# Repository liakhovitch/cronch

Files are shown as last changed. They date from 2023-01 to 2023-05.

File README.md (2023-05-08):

# Crönch!
Not-entirely-sane digital delay pedal

**Note: This project is a work in progress!**

## What is this?
Crönch is a hardware audio effects processor unit, inspired by the Sonic Charge Permut8 software plugin. For a more detailed explanation, see [the proposal document](proposal/proposal.pdf).

Some key points:
- Hardware designed in KiCAD
- Firmware written in Rust
- Based on the RP2040 microcontroller and TI TLV320AIC3254 audio CODEC
- Runs at a 192KHz audio sampling rate

## Repository map
[Schematic](pcb/effectpedal/fabrication/schematic.pdf)

[Firmware](firmware/src)

[Original proposal](proposal/proposal.pdf)

## Todo
- [x] Preliminary design
- [X] Choosing components
- [X] Electrical design (schematic)
- [X] PCB design
- [X] Hardware assembly
- [X] Basic hardware test (MCU can read/write from each external peripheral)
- [X] Full hardware test (MCU can access all features of each external peripheral)
- [X] Multicore concurrency primitives
- [X] Front panel UI
- [ ] All hardware driver code complete
- [ ] Basic functionality (Sample incoming audio, write it to the buffer, then immediately send it back to the CODEC)
- [ ] All operators implemented
- [ ] All audio knobs (mix, feedback, gain, etc) implemented
- [ ] Variable clock rate

## Images
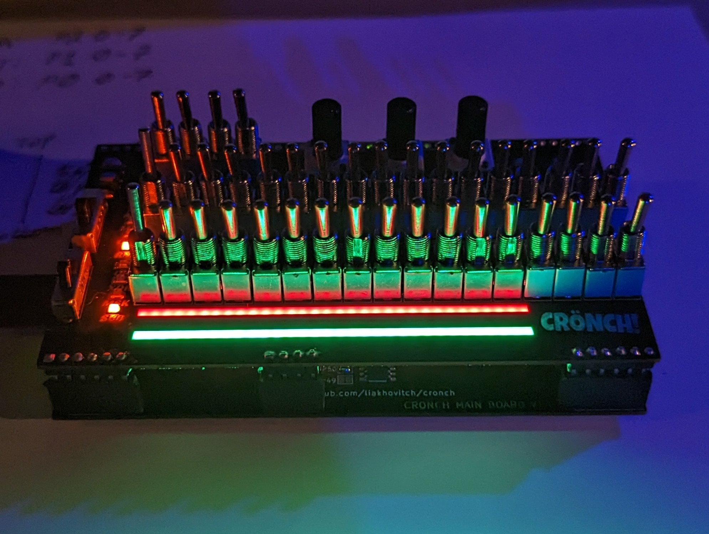
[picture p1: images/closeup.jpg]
Side

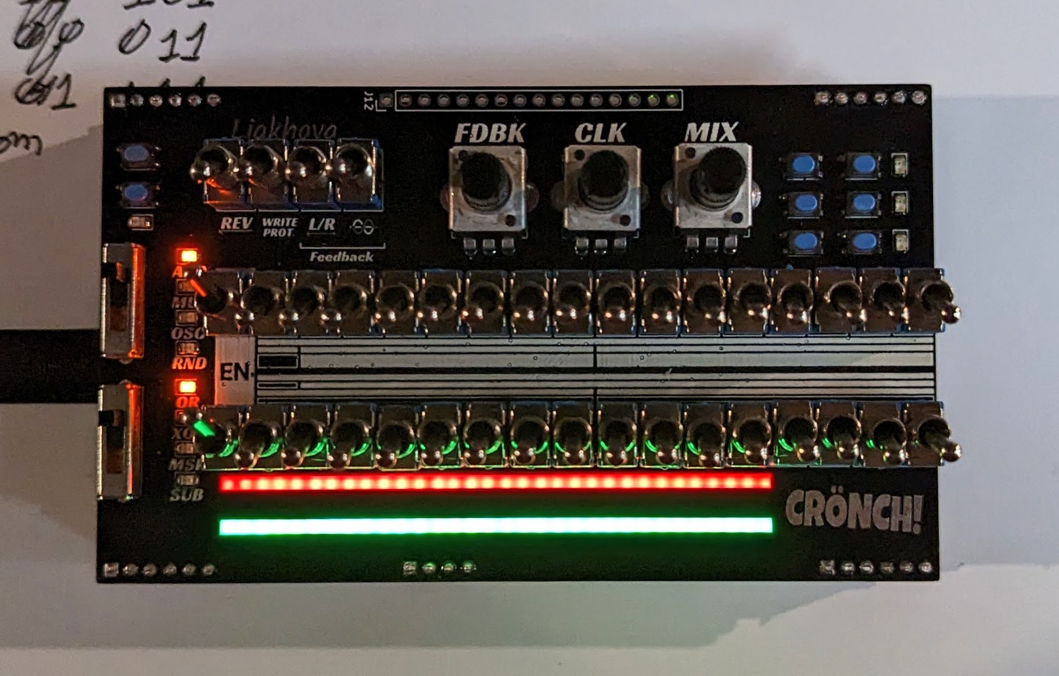
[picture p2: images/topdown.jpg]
Front

### Bonus: I built a reflow oven!
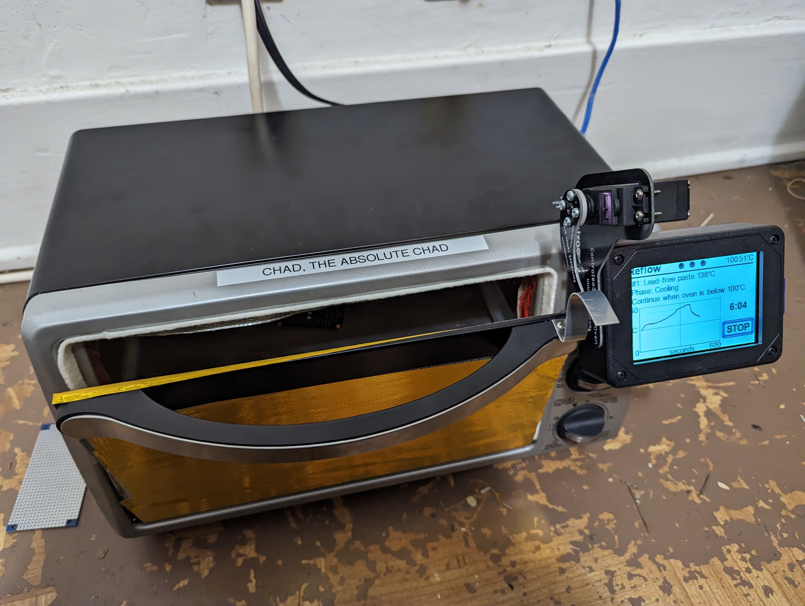
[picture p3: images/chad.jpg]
Chad, the Absolute Chad


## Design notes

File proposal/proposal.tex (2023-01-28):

\documentclass[12pt, letterpaper]{article}
\usepackage[letterpaper, margin=1in]{geometry} % Decrease page margins
\title{ECE Project Proposal: Audio Effects Box}
\author{Anton Liakhovitch}

\usepackage{graphicx}
\graphicspath{{images/}}
\usepackage[defaultlines=4,all]{nowidow} % Discourage paragraph breaks across pages
\usepackage[skip=10pt plus1pt, indent=0pt]{parskip}
\usepackage[british]{babel}

\newcommand{\lbr}{\\[12pt]}
\renewcommand\labelitemi{--} % Use dashes in lists

\begin{document}
\maketitle
\section{Background}
\par
Music producers employ a variety of effects in order to improve or modify their audio. Effects normally take one of two forms: \textit{effects plugins}, and \textit{effects boxes} (also known as \textit{effects pedals}).
\par
An effect plugin is computer software which integrates with a \textit{digital audio workstation} (DAW) program via one of several standard plugin protocols. The DAW allows the producer to compose and record music, while plugins provide effects and other tools.
\par
An effects box is a physical device which normally includes at least one audio input and one audio output. The box applies a given effect to the incoming audio signal in real time. For example, a delay pedal might add in delayed copies of the original signal for an 'echo' effect. Many software plugins use 'virtual analog' algorithms to emulate well-known physical effects boxes.
\par
Sonic Charge - a music software company - makes an effect plugin called \textit{Permut8}. The user interface is visible in Figure~\ref{fig:permut8}. On the left, a virtual analog section allows for basic mixing and filtering operations. On the right side, a digital section allows for manipulation of the signal to create various 'glitch' effects. The plugin is intentially made to look and behave like an emulation of a physical effects box - however, no physical version of Permut8 has ever been built.

\section{Goal}
\par
This project aims to create a physical effects processing box with similar functionality to Sonic Charge's Permut8 software plugin. The scope of the project covers only the \textit{digital section} of Permut8; the 'virtual analog' section is mostly out of scope and may be added later through updated hardware or software.
\begin{figure}
  \centering
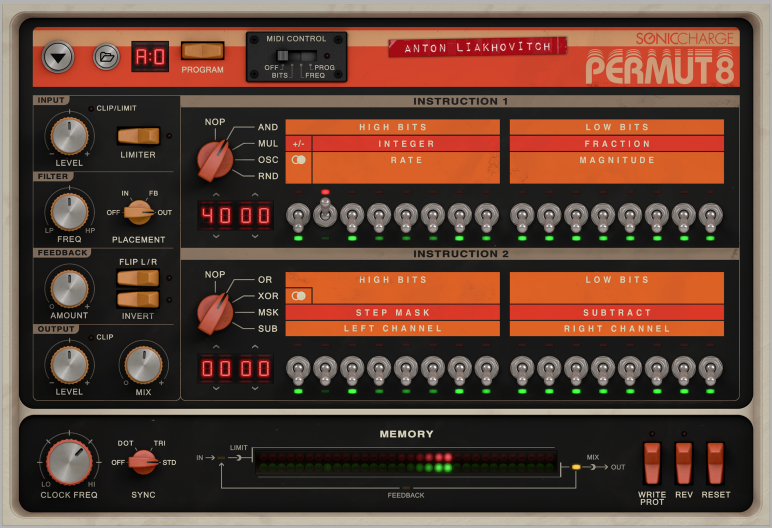
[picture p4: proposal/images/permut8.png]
  
  \caption{Sonic Charge 'Permut8' Effects Plugin}
  \label{fig:permut8}
\end{figure}

\section{Functionality}
\par
Permut8, the original inspiration for this project, is a form of digital delay effect. The plugin is designed as a software emulation of a fictional piece of hardware. This section provides a brief summary of this fictional hardware. For detailed information, see the \textit{Permut8 User Guide}.
\subsection{Buffer}
\par
At the core of Permut8 is a memory buffer which stores 128,000 audio samples. The device is clocked at a variable rate, ranging from 0 to 352.8KHz. On each cycle, audio is sampled from the input and written to the buffer. Then, a sample is read from the buffer and sent to the output. The \textit{write address} increments by one every clock cycle and wraps around to zero at the end of the buffer. By default, the \textit{read address} is the same as the write address. Thus, by default, the plugin makes no changes to the incoming audio - it records an input sample into a buffer, then reads and outputs the same sample. In the interface (Figure~\ref{fig:permut8}), the read and write positions are visible on the 'LED bar' at the bottom.
\lbr
The behavior is analogous to a loop of tape, where a write head is placed immediately in front of a read head.
\subsection{Operations}
Permut8 can apply up to two \textit{operations} to the read address in order to make the output more interesting \footnote{The Permut8 manual refers to these operations as "instructions".}. For example, the "SUB" operator subtracts a fixed value from the read address. This makes the read position lag behind the write position by some amount of time, thereby delaying the output signal. The rows of switches seen in Figure~\ref{fig:permut8} configure input parameters for the operators.
\subsection{Mixer}
While the mixer is part of the 'virtual analog section', it is simple to emulate digitally. The mixer includes several controls:
\begin{itemize}
\item \textit{Output level} controls the output audio level.
\item \textit{Mix} controls how much of the original, unmodified signal is mixed into the output.
\item \textit{Feedback} controls how much of the output signal is mixed back into the input.
\end{itemize}
\section{Project Scope}
This project aims to implement most of the functionality of Permut8's 'digital' section, and some of the functionality of the 'analog' section. This includes:
\begin{itemize}
  \item The audio buffer.
  \item Both operators, with all available operations.
  \item Variable audio clock frequency \footnote{This refers to the processing algorithm only - it does not need to correspond to any actual hardware clock frequencies.}.
  \item Write protect, reverse, and reset switches.
  \item Stereo audio processing.
  \item The three mixer knobs (\textit{output level}, \textit{mix}, and \textit{feedback}).
  \item The 'invert' and 'flip L/R' switches for feedback.
\end{itemize}
Notable omissions:
\begin{itemize}
  \item The analog filter and limiter, and the input level knob.
  \item Tempo sync functionality.
  \item Preset-saving functionality.
  \item Hexadecimal operand indicator displays.
\end{itemize}
There are also additional requirements based on practical considerations of physical hardware development:
\begin{itemize}
  \item Standard connectors (1/4 inch or 1/8 inch TRS) for audio in/out)
  \item 16-bit or 32-bit DAC and ADC \footnote{The original Permut8 uses 12-bit audio. 24-bit is generally considered the highest resolution detectable by humans. However, extra resolution is useful in a hardware context because it allows for a wide range of input levels.}.
\end{itemize}

\section{Basic Design}
The draft design described here is subject to change, and should only be used to gain an understanding of the technologies and challenges involved in the project.
\par
The device will be based on a readily available 32-bit ARM MCU - for example, the STM32\-F411 or the RP\-2040. The MCU will communicate with a stereo ADC/DAC IC over an I2S (or similar) interface. The audio buffer will be stored in an external RAM module, connected via either a parallel or SPI interface. Buttons, knobs, and LEDs will be accessed via a chain of shift registers. Firmware will be written in Rust.
\begin{figure}[!ht]
  \centering
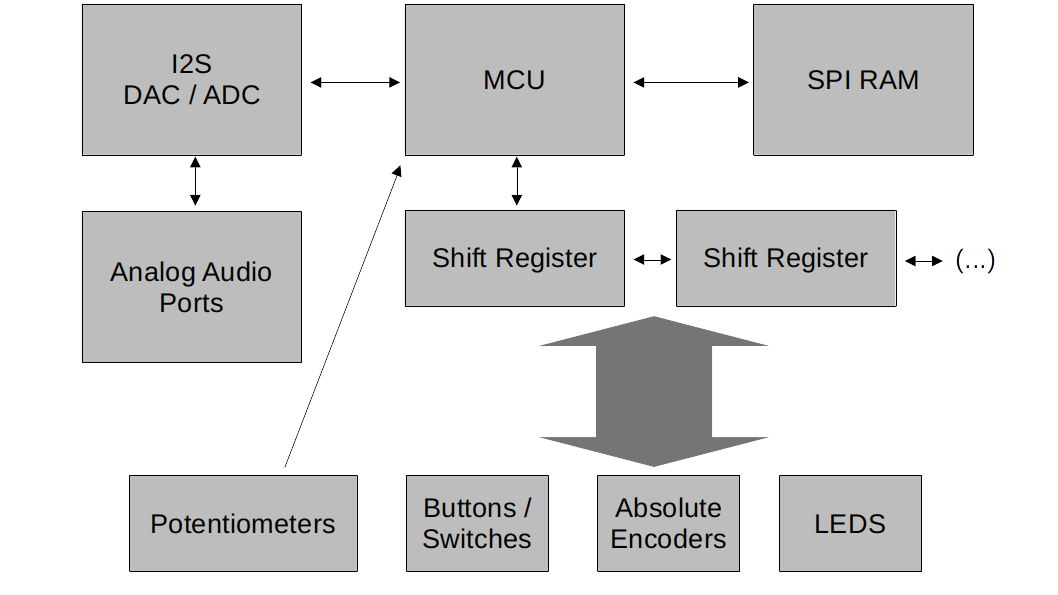
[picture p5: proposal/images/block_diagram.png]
  
  \caption{High-level Hardware Diagram}
  \label{fig:block_diagram}
\end{figure}

\section{Optional Features}
Additional features may be added once the rest of the project is complete. These features are optional, and no time should be spent on them until the rest of the project is done - however, some consideration may be put into forwards compatibility so that they can be easily added later. Potential optional features include:
\begin{itemize}
  \item A display, encoder, and button which may be used to control menus.
  \item Tempo sync functionality (MIDI, MIDI-over-USB, or clock-pulse-over-TRS).
  \item The filter and limiter, as software or as analog circuits.
  \item A headphone amplifier \footnote{This may turn out to be trivial, depending on the capabilities of the chosen DAC.}.
\end{itemize}

\end{document}

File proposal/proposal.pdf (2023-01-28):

# ECE Project Proposal: Audio Effects Box

### Anton Liakhovitch

### 27th November 2022

## 1 Background

Music producers employ a variety of effects in order to improve or modify their audio. Effects normally take one of two forms: effects plugins, and effects boxes (also known as effects pedals).

An effect plugin is computer software which integrates with a digital audio workstation (DAW) program via one of several standard plugin protocols. The DAW allows the producer to compose and record music, while plugins provide effects and other tools.

An effects box is a physical device which normally includes at least one audio input and one audio output. The box applies a given effect to the incoming audio signal in real time. For example, a delay pedal might add in delayed copies of the original signal for an ’echo’ effect. Many software plugins use ’virtual analog’ algorithms to emulate well-known physical effects boxes.

Sonic Charge - a music software company - makes an effect plugin called Permut8. The user interface is visible in Figure 1. On the left, a virtual analog section allows for basic mixing and filtering operations. On the right side, a digital section allows for manipulation of the signal to create various ’glitch’ effects. The plugin is intentially made to look and behave like an emulation of a physical effects box - however, no physical version of Permut8 has ever been built.

## 2 Goal

This project aims to create a physical effects processing box with similar functionality to Sonic Charge’s Permut8 software plugin. The scope of the project covers only the digital section of Permut8; the ’virtual analog’ section is mostly out of scope and may be added later through updated hardware or software.


Figure 1: Sonic Charge ’Permut8’ Effects Plugin

## 3 Functionality

Permut8, the original inspiration for this project, is a form of digital delay effect. The plugin is designed as a software emulation of a fictional piece of hardware. This section provides a brief summary of this fictional hardware. For detailed information, see the Permut8 User Guide.

### 3.1 Buffer

At the core of Permut8 is a memory buffer which stores 128,000 audio samples. The device is clocked at a variable rate, ranging from 0 to 352.8KHz. On each cycle, audio is sampled from the input and written to the buffer. Then, a sample is read from the buffer and sent to the output. The write address increments by one every clock cycle and wraps around to zero at the end of the buffer. By default, the read address is the same as the write address. Thus, by default, the plugin makes no changes to the incoming audio - it records an input sample into a buffer, then reads and outputs the same sample. In the interface (Figure 1), the read and write positions are visible on the ’LED bar’ at the bottom.

The behavior is analogous to a loop of tape, where a write head is placed immediately in front of a read head.

### 3.2 Operations

Permut8 can apply up to two operations to the read address in order to make the output more interesting 1
. For example, the ”SUB” operator subtracts a fixed value from the read address. This makes the read position lag behind the write position by some amount of time, thereby delaying the output signal. The rows of switches seen in Figure 1 configure input parameters for the operators.

### 3.3 Mixer

While the mixer is part of the ’virtual analog section’, it is simple to emulate digitally. The mixer includes several controls:

– Output level controls the output audio level.

– Mix controls how much of the original, unmodified signal is mixed into the output.

– Feedback controls how much of the output signal is mixed back into the input.

## 4 Project Scope

This project aims to implement most of the functionality of Permut8’s ’digital’ section, and some of the functionality of the ’analog’ section. This includes:

– The audio buffer.

– Both operators, with all available operations.

– Variable audio clock frequency 2

– Write protect, reverse, and reset switches.

– Stereo audio processing.

– The three mixer knobs (output level, mix, and feedback).

– The ’invert’ and ’flip L/R’ switches for feedback.

Notable omissions:

– The analog filter and limiter, and the input level knob.

– Tempo sync functionality.

– Preset-saving functionality.

1The Permut8 manual refers to these operations as ”instructions”.
2This refers to the processing algorithm only - it does not need to correspond to any actual hardware clock frequencies.

– Hexadecimal operand indicator displays.

There are also additional requirements based on practical considerations of physical hardware development:

– Standard connectors (1/4 inch or 1/8 inch TRS) for audio in/out)

– 16-bit or 32-bit DAC and ADC 3

## 5 Basic Design

The draft design described here is subject to change, and should only be used to gain an understanding of the technologies and challenges involved in the project.

The device will be based on a readily available 32-bit ARM MCU - for example, the STM32-F411 or the RP2040. The MCU will communicate with a stereo ADC/DAC IC over an I2S (or similar) interface. The audio buffer will be stored in an external RAM module, connected via either a parallel or SPI interface. Buttons, knobs, and LEDs will be accessed via a chain of shift registers. Firmware will be written in Rust.

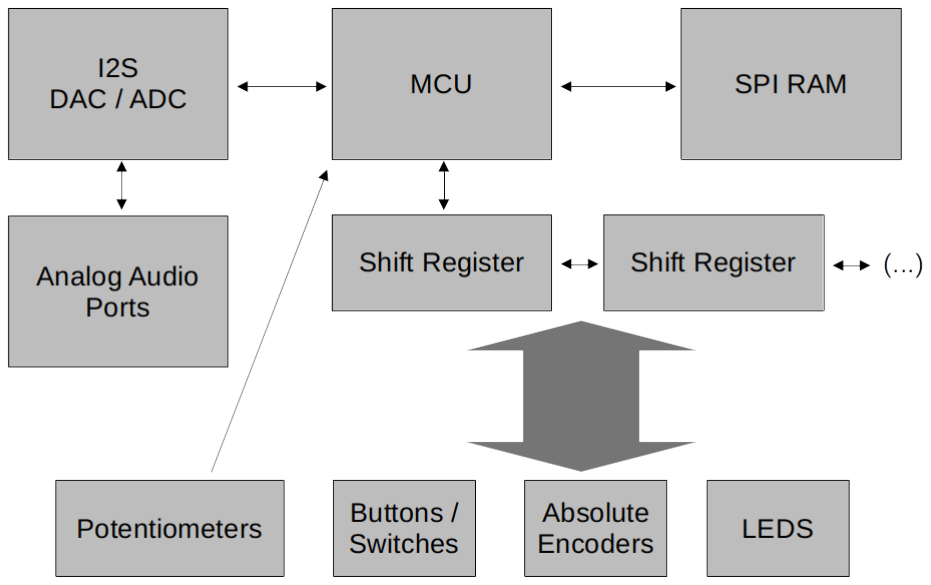
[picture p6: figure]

Figure 2: High-level Hardware Diagram

3The original Permut8 uses 12-bit audio. 24-bit is generally considered the highest resolution detectable by humans. However, extra resolution is useful in a hardware context because it allows for a wide range of input levels.

## 6 Optional Features

Additional features may be added once the rest of the project is complete. These features are optional, and no time should be spent on them until the rest of the project is done -however, some consideration may be put into forwards compatibility so that they can be easily added later. Potential optional features include:

– A display, encoder, and button which may be used to control menus.

– Tempo sync functionality (MIDI, MIDI-over-USB, or clock-pulse-over-TRS).

– The filter and limiter, as software or as analog circuits.

– A headphone amplifier 4

4This may turn out to be trivial, depending on the capabilities of the chosen DAC.

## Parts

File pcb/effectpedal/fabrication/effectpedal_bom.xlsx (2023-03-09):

 | EFFECTPEDAL BOM V1.0
Quantity | Designator | Description | Value | Footprint | Manufacturer | Part Number | DigiKey Link | DigiKey PN (tape)
6 | C1, C2, C3, C4, C5, C6 | Tolerance 10%, low A/V | 47u | 1210 | Murata Electronics | GRM32EC81C476KE15K | https://www.digikey.com/en/products/detail/murata-electronics/GRM32EC81C476KE15K/7363053 | 490-16309-2-ND
10 | C7, C8, C9, C10, C11, C14, C15, C16, C17, C18 | Tolerance 10%, low A/V | 0.1u | 0805 | KYOCERA AVX | 08055C104KAT2A | https://www.digikey.com/en/products/detail/kyocera-avx/08055C104KAT2A/563505 | 478-1395-2-ND
2 | C12, C13 | Tolerance 10%, low A/V | 33p | 0805 | KYOCERA AVX | 08055A330JAT2A | https://www.digikey.com/en/products/detail/kyocera-avx/08055A330JAT2A/563420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 | 478-1310-2-ND
4 | D1, D2, D3, D4 | Forward voltage < 500mV | D_Schottky | 0805 | KYOCERA AVX | SD0805S020S1R0 | https://www.digikey.com/en/products/detail/kyocera-avx/SD0805S020S1R0/3749517 | 478-7800-2-ND
12 | D5, D6, D7, D8, D9, D10, D11, D12, D13, D14, D15, D16 | LED, orange, 20mA | LED, orange | 0805 | Venkel | CTL0805FOG1T | https://www.digikey.com/en/products/detail/venkel/CTL0805FOG1T/13245036 | 2679-CTL0805FOG1TTR-ND
32 | D17, D18, D19, D20, D21, D22, D23, D24, D25, D26, D27, D28, D29, D30, D31, D32, D33, D34, D35, D36, D37, D38, D39, D40, D41, D42, D43, D44, D45, D46, D47, D48 | LED, red, 20mA | LED, red | 0805 | Würth Elektronik | 150080RS75000 | https://www.digikey.com/en/products/detail/w%C3%BCrth-elektronik/150080RS75000/4489918 | 732-4984-2-ND
32 | D49, D50, D51, D52, D53, D54, D55, D56, D57, D58, D59, D60, D61, D62, D63, D64, D65, D66, D67, D68, D69, D70, D71, D72, D73, D74, D75, D76, D77, D78, D79, D80 | LED, green, 20mA | LED, green | 0805 | Würth Elektronik | 150080GS75000 | https://www.digikey.com/en/products/detail/w%C3%BCrth-elektronik/150080GS75000/4489915 | 732-4983-2-ND
1 | IC1 | SRAM 16Mb, SerialRAM, 1.65V-1.95V, 104MHz, 8 pin SOIC 150 mil, RoHS | IS66WVS2M8ALL-104NLI | SOIC127P600X175-8N | Integrated Silicon Solution Inc. | IS66WVS2M8ALL-104NLI | https://www.digikey.com/en/products/detail/issi-integrated-silicon-solution-inc/IS66WVS2M8ALL-104NLI/16260614 | 706-IS66WVS2M8ALL-104NLI-ND
1 | IC2 | Interface - I/O Expanders PCAL6524HE/HUQFN32///REEL 7 Q2/T3 *STANDARD MARK | PCAL6524HEAZ | QFN50P500X500X60-33N-D | NXP | PCAL6524HEAZ | https://www.digikey.com/en/products/detail/nxp-usa-inc/PCAL6524HEAZ/5823391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 | 568-12879-2-ND
1 | IC3 | Interface - I/O Expanders PCAL6524HE/HUQFN32///REEL 7 Q2/T3 *STANDARD MARK | PCAL6524HEAZ | QFN50P500X500X60-33N-D | NXP | PCAL6524HEAZ | https://www.digikey.com/en/products/detail/nxp-usa-inc/PCAL6524HEAZ/5823391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 | 568-12879-2-ND
1 | IC4 | Interface - I/O Expanders PCAL6524HE/HUQFN32///REEL 7 Q2/T3 *STANDARD MARK | PCAL6524HEAZ | QFN50P500X500X60-33N-D | NXP | PCAL6524HEAZ | https://www.digikey.com/en/products/detail/nxp-usa-inc/PCAL6524HEAZ/5823391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 | 568-12879-2-ND
1 | IC5 | LED Lighting Drivers Audio Mod Matrix LED Driver | IS31FL3728-QFLS2-TR | QFN50P400X400X80-25N-D | Integrated Silicon Solution Inc. | IS31FL3728-QFLS2-TR | https://www.digikey.com/en/products/detail/lumissil-microsystems/IS31FL3728-QFLS2-TR/5319755 | 2521-IS31FL3728-QFLS2-TR-ND
3 | J1, J2, J3 | 4 conductor 3.5 mm Surface Mount Audio Jack w/ Ring Switch | SJ-43515RS-SMT-TR | SJ43515RSSMTTR | CUI Devices | SJ-43515RS-SMT-TR | https://www.digikey.com/en/products/detail/cui-devices/SJ-43515RS-SMT-TR/669722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 | CP-43515RSSJTR-ND
2 | R1, R2 | Tolerance 10%, low A/V | 10k | 0805 | YAGEO | RC0805JR-0710KL | https://www.digikey.com/en/products/detail/yageo/RC0805JR-0710KL/728241 | 311-10KARTR-ND
4 | R3, R5, R6, R7 | Tolerance 2%, low A/V | 27 | 0805 | YAGEO | RC0805FR-0727RL | https://www.digikey.com/en/products/detail/yageo/RC0805FR-0727RL/727779 | 311-27.0CRTR-ND
1 | R4 | Tolerance 2%, low A/V | 10 | 0805 | YAGEO | RC0805FR-1010RL | https://www.digikey.com/en/products/detail/yageo/RC0805FR-1010RL/13694222 | 13-RC0805FR-1010RLTR-ND
4 | R8, R9, R10, R11 | Tolerance 10%, low A/V | 4k | 0805 | YAGEO | RC0805JR-074K3L | https://www.digikey.com/en/products/detail/yageo/RC0805JR-074K3L/728324 | 311-4.3KARTR-ND
12 | R12, R13, R14, R15, R16, R17, R18, R19, R20, R21, R22, R23 | Tolerance 2%, low A/V | 150 | 0805 | YAGEO | RC0805FR-07150RL | https://www.digikey.com/en/products/detail/yageo/RC0805FR-07150RL/727613 | 311-150CRTR-ND
3 | RV1, RV2, RV3 | Potentiometer | R_Potentiometer_US | PTV09A4015FB103 | Bourns Inc. | PTV09A-4015F-B103 | https://www.digikey.com/en/products/detail/bourns-inc/PTV09A-4015F-B103/3781113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 | PTV09A-4015F-B103-ND
38 | S1, S2, S3, S4, S5, S6, S7, S8, S9, S10, S11, S12, S13, S14, S15, S16, S17, S18, S19, S20, S21, S22, S23, S24, S25, S26, S27, S28, S29, S30, S31, S32, S33, S34, S35, S36, S37, S38 | Toggle Switch | SW-T3-2B-A-A3-S1 | SW-T3-2B-A-A3-S1 | Adam Tech | SW-T3-2B-A-A3-S1 | https://www.digikey.com/en/products/detail/adam-tech/SW-T3-2B-A-A3-S1/15284416 | 2057-SW-T3-2B-A-A3-S1-ND
1 | S39 | Slide Switches | OP1 op sel | SS14D0839VG5PA | C & K COMPONENTS | SS14D0839VG5PA | https://www.digikey.com/en/products/detail/c-k/SS-14D0839-VG-5-PA/6166625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 | CKN10727-ND
1 | S40 | Slide Switches | OP2 op sel | SS14D0839VG5PA | C & K COMPONENTS | SS14D0839VG5PA | https://www.digikey.com/en/products/detail/c-k/SS-14D0839-VG-5-PA/6166625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 | CKN10727-ND
8 | SW1, SW2, SW3, SW4, SW5, SW6, SW7, SW8 | Tactile switch | SW_SPST | PTS810SJG250SMTRLFS | C & K COMPONENTS | PTS810 SJG 250 SMTR LFS | https://www.digikey.com/en/products/detail/c-k/PTS810-SJG-250-SMTR-LFS/4176612 | CKN10504TR-ND
1 | U1 | Audio CODEC | TLV320AIC3254IRHBT | QFN50P500X500X100-33N | Texas Instruments | TLV320AIC3254IRHBT | https://www.digikey.com/en/products/detail/texas-instruments/TLV320AIC3254IRHBR/1952546 | 296-23776-2-ND
1 | U2 | Raspberry Pi Pico RP2040 development board | Pi Pico | MODULE_SC0915 | Raspberry Pi | SC0915 | https://www.digikey.com/en/products/detail/raspberry-pi/SC0915/13624793 | 2648-SC0915TR-ND
1 | U3 | Raspberry Pi Pico RP2040 development board | Pi Pico | MODULE_SC0915 | Raspberry Pi | SC0915 | https://www.digikey.com/en/products/detail/raspberry-pi/SC0915/13624793 | 2648-SC0915TR-ND

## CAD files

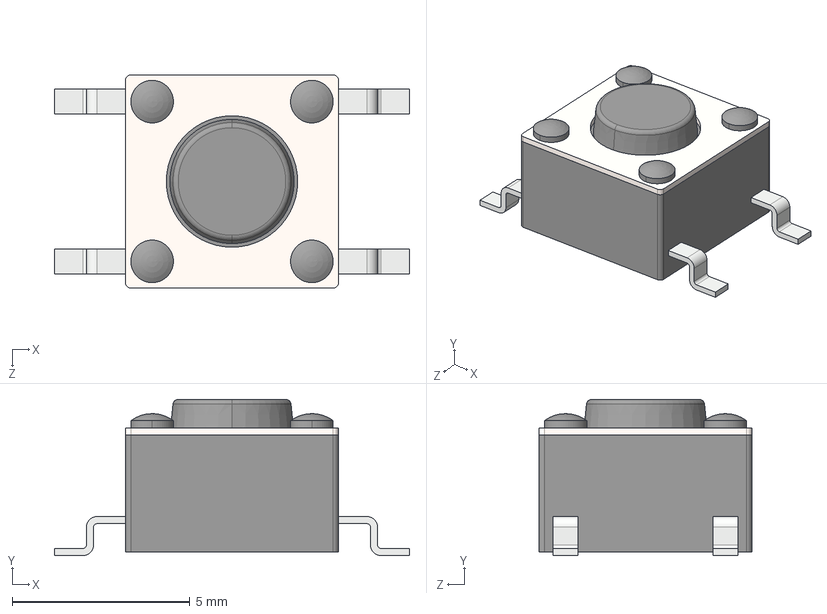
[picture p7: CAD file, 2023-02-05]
pcb/effectpedal/footprints/CUI_DEVICES_TS04-66-43-BK-100-SMT.step
10.0 x 4.40 x 6.00 mm

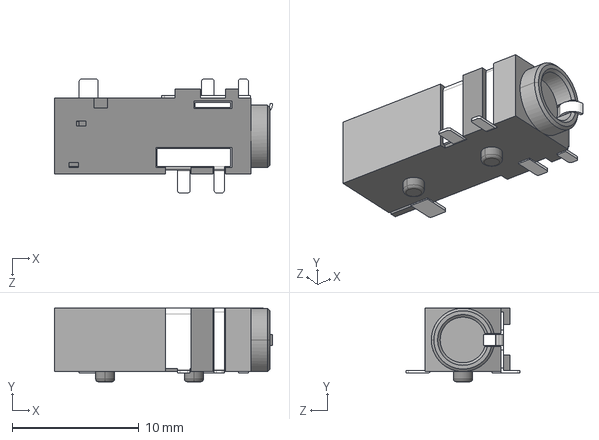
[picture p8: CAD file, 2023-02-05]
pcb/effectpedal/footprints/SJ-43515RS-SMT-TR.stp
17.2 x 5.80 x 9.00 mm

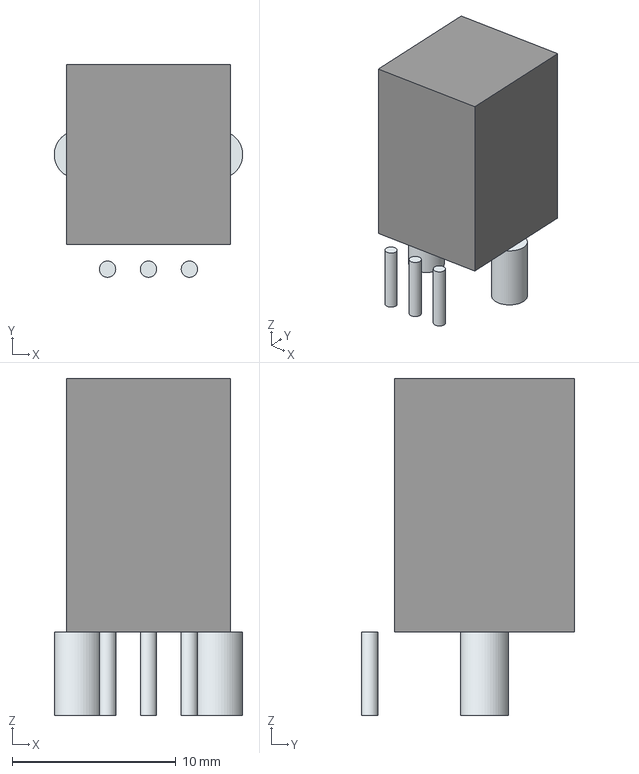
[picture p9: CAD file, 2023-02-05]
pcb/effectpedal/footprints/PTV09A-4020U-B103.stp
11.5 x 13.0 x 20.6 mm
Leads x 5

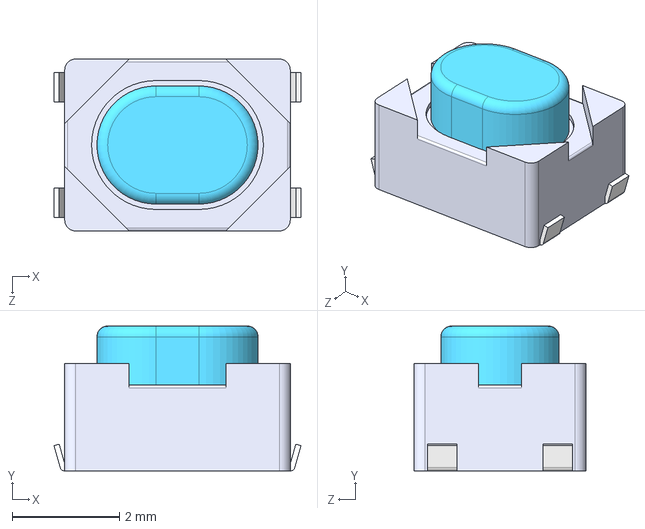
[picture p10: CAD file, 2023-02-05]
pcb/effectpedal/footprints/PTS810SJK250SMTRLFS.step
4.60 x 2.70 x 3.20 mm

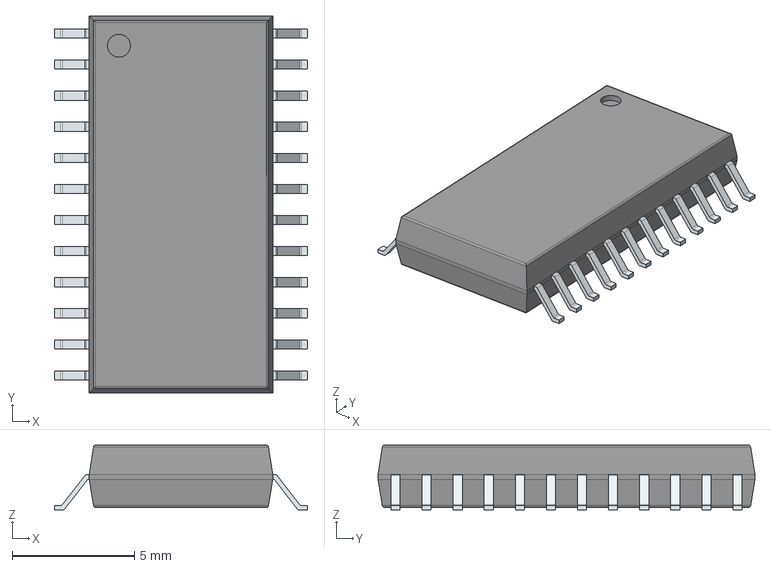
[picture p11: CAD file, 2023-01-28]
pcb/effectpedal/footprints/IS31FL3218-GRLS2.stp
10.4 x 15.4 x 2.65 mm
PinsArrayLR

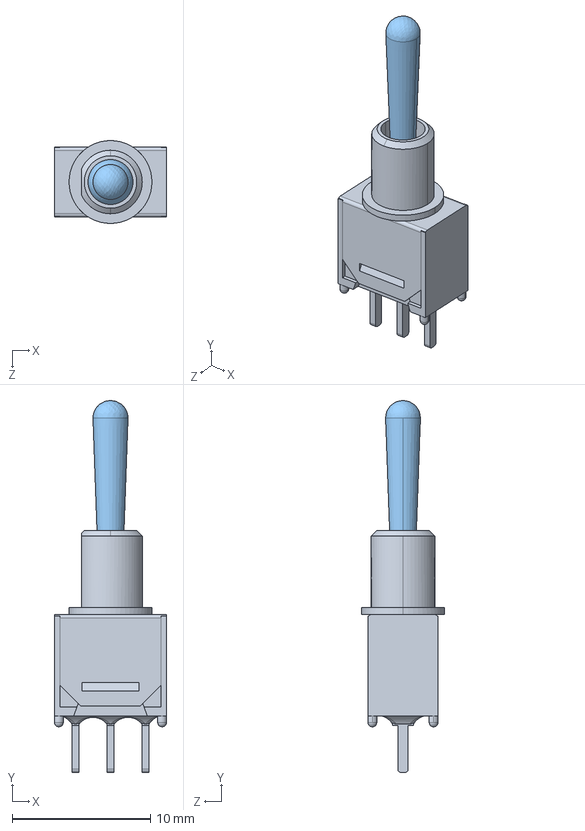
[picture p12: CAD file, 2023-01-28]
pcb/effectpedal/footprints/SW-T3-2B-A-A3-S1.stp
8.13 x 26.9 x 6.00 mm

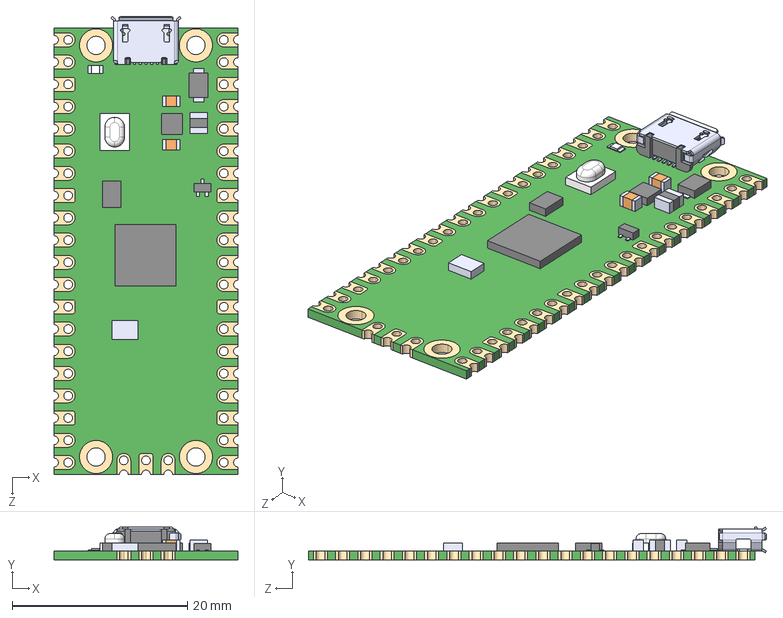
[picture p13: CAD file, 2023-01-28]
pcb/effectpedal/footprints/SC0915.stp
21.0 x 3.73 x 52.3 mm

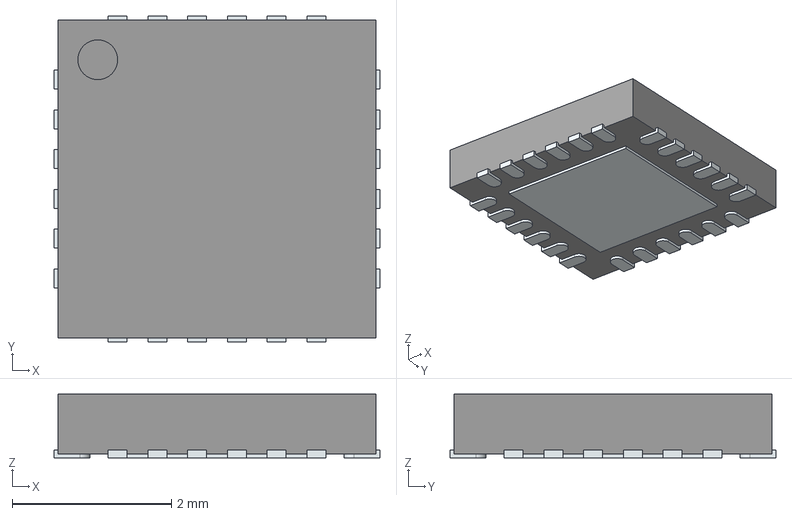
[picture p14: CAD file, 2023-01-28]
pcb/effectpedal/footprints/IS31FL3728-QFLS2-TR.stp
4.10 x 4.10 x 0.8 mm
ThermalPin
PinsArrayLR
PinsArrayTB

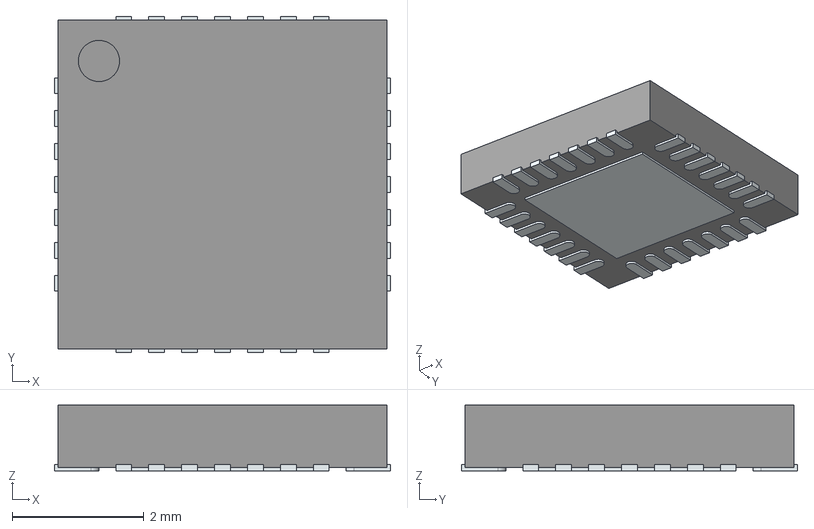
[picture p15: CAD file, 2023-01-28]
pcb/effectpedal/footprints/ECE1088-DZK.stp
5.10 x 5.10 x 1.00 mm
ThermalPin
PinsArrayLR
PinsArrayTB

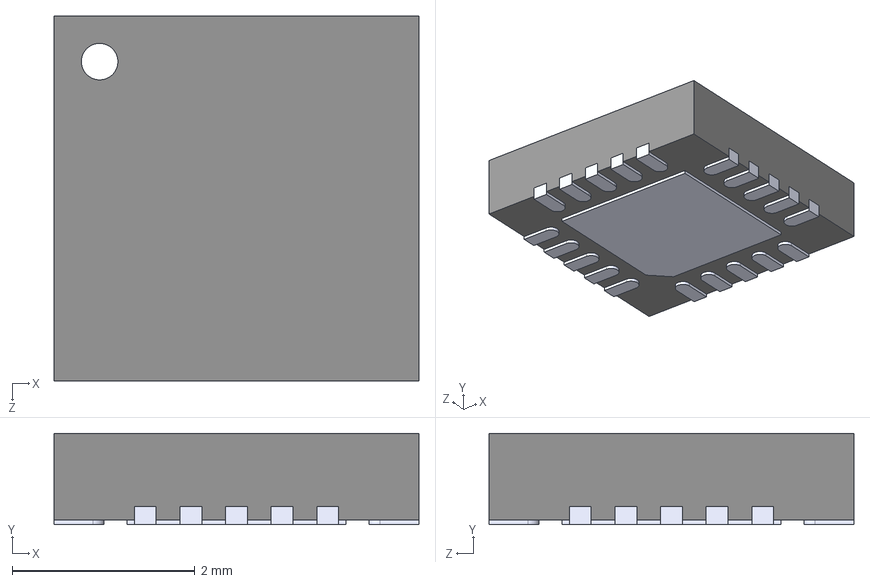
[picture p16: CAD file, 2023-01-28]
pcb/effectpedal/footprints/TLV320AIC3254IRHBT.stp
4.00 x 1.00 x 4.00 mm

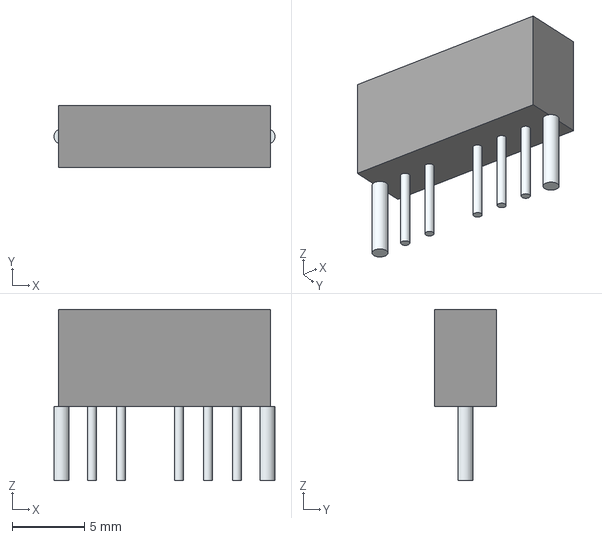
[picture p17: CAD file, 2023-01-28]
pcb/effectpedal/footprints/SS14D0839VG5PA.stp
15.2 x 4.30 x 11.8 mm
Leads x 7

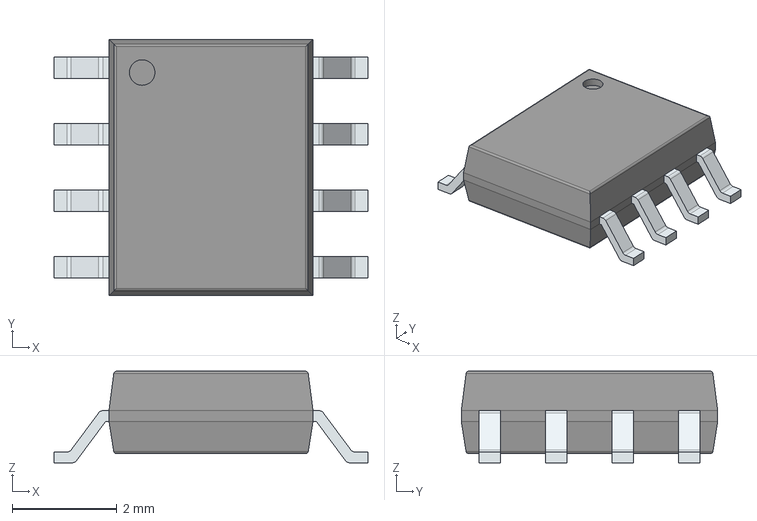
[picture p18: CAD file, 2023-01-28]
pcb/effectpedal/footprints/IS66WVS2M8ALL-104NLI.stp
6.00 x 4.90 x 1.75 mm
PinsArrayLR

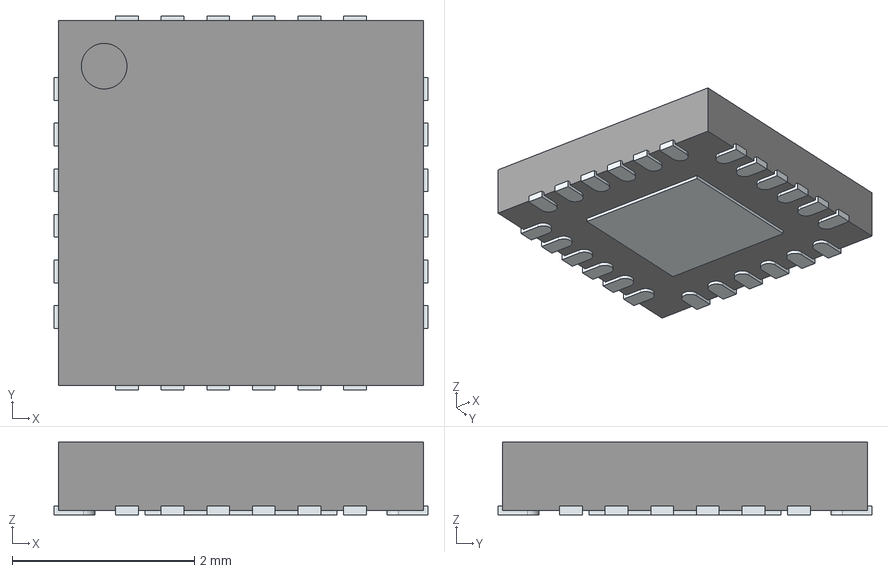
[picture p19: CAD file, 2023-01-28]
pcb/effectpedal/footprints/ADP5587ACPZ-R7.stp
4.10 x 4.10 x 0.8 mm
ThermalPin
PinsArrayLR
PinsArrayTB

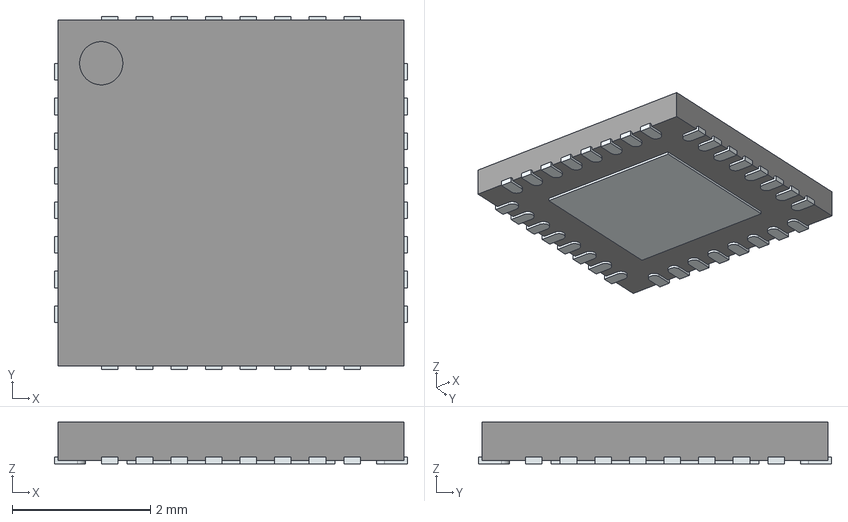
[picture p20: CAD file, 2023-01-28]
pcb/effectpedal/footprints/PCAL6524HEAZ.stp
5.10 x 5.10 x 0.6 mm
ThermalPin
PinsArrayLR
PinsArrayTB

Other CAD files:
pcb/effectpedal/footprints/SJ2-3574A-SMT-TR.stp

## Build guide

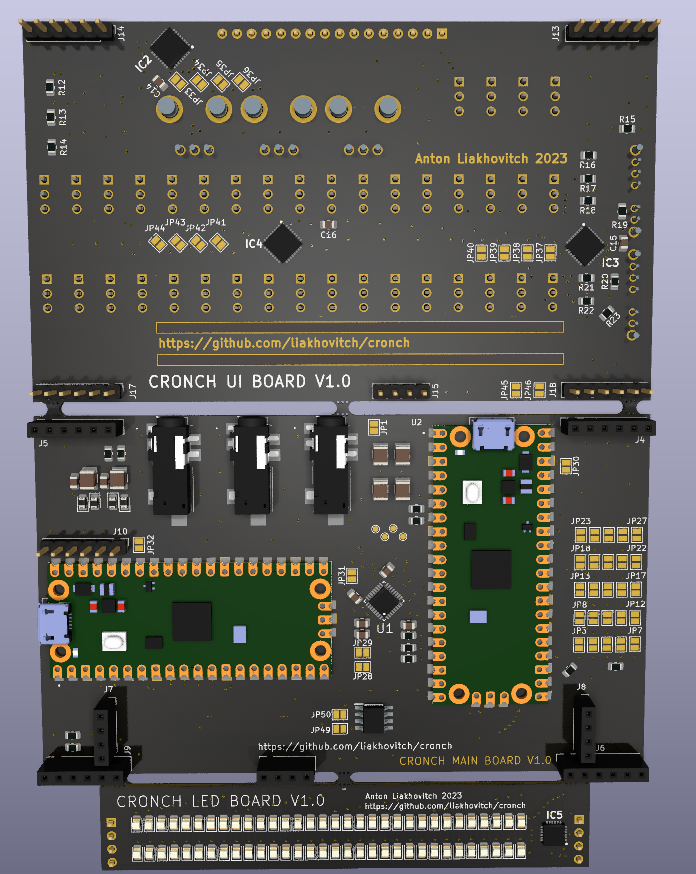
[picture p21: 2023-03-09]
pcb/effectpedal/fabrication/3d_front.png

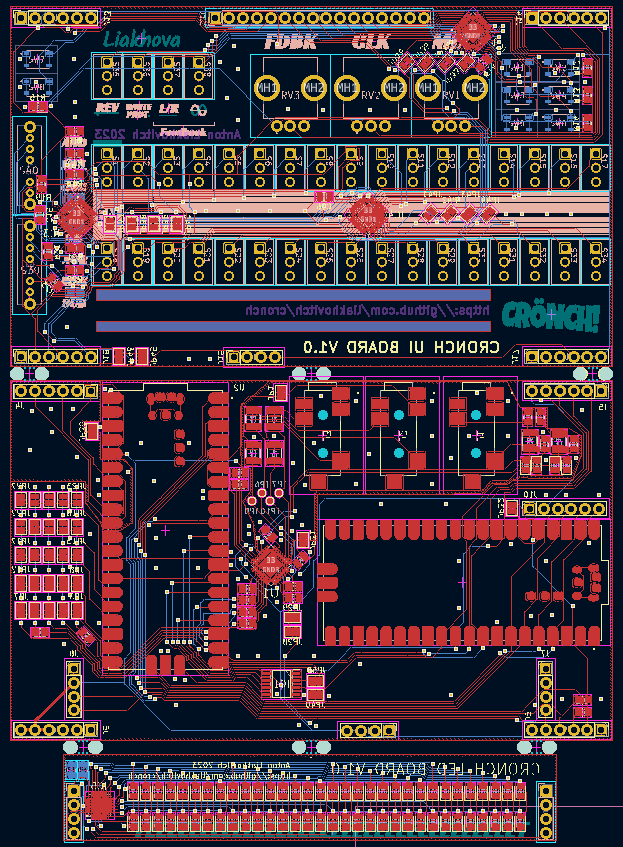
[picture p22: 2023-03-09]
pcb/effectpedal/fabrication/layout.png

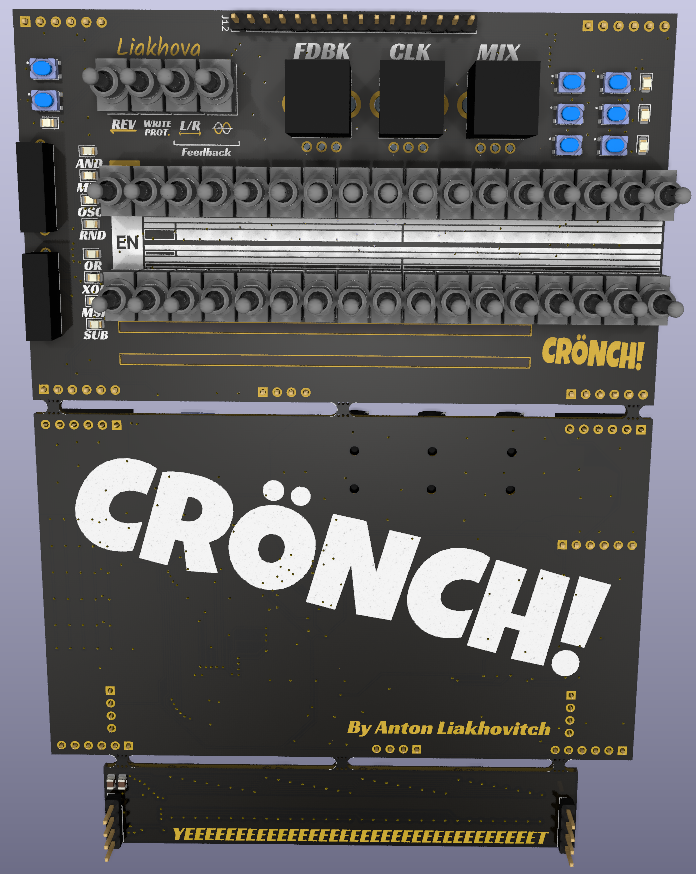
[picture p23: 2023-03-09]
pcb/effectpedal/fabrication/3d_back.png

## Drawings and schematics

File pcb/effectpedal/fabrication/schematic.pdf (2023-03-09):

| | 10k C1 10k D3 D2

# Headset

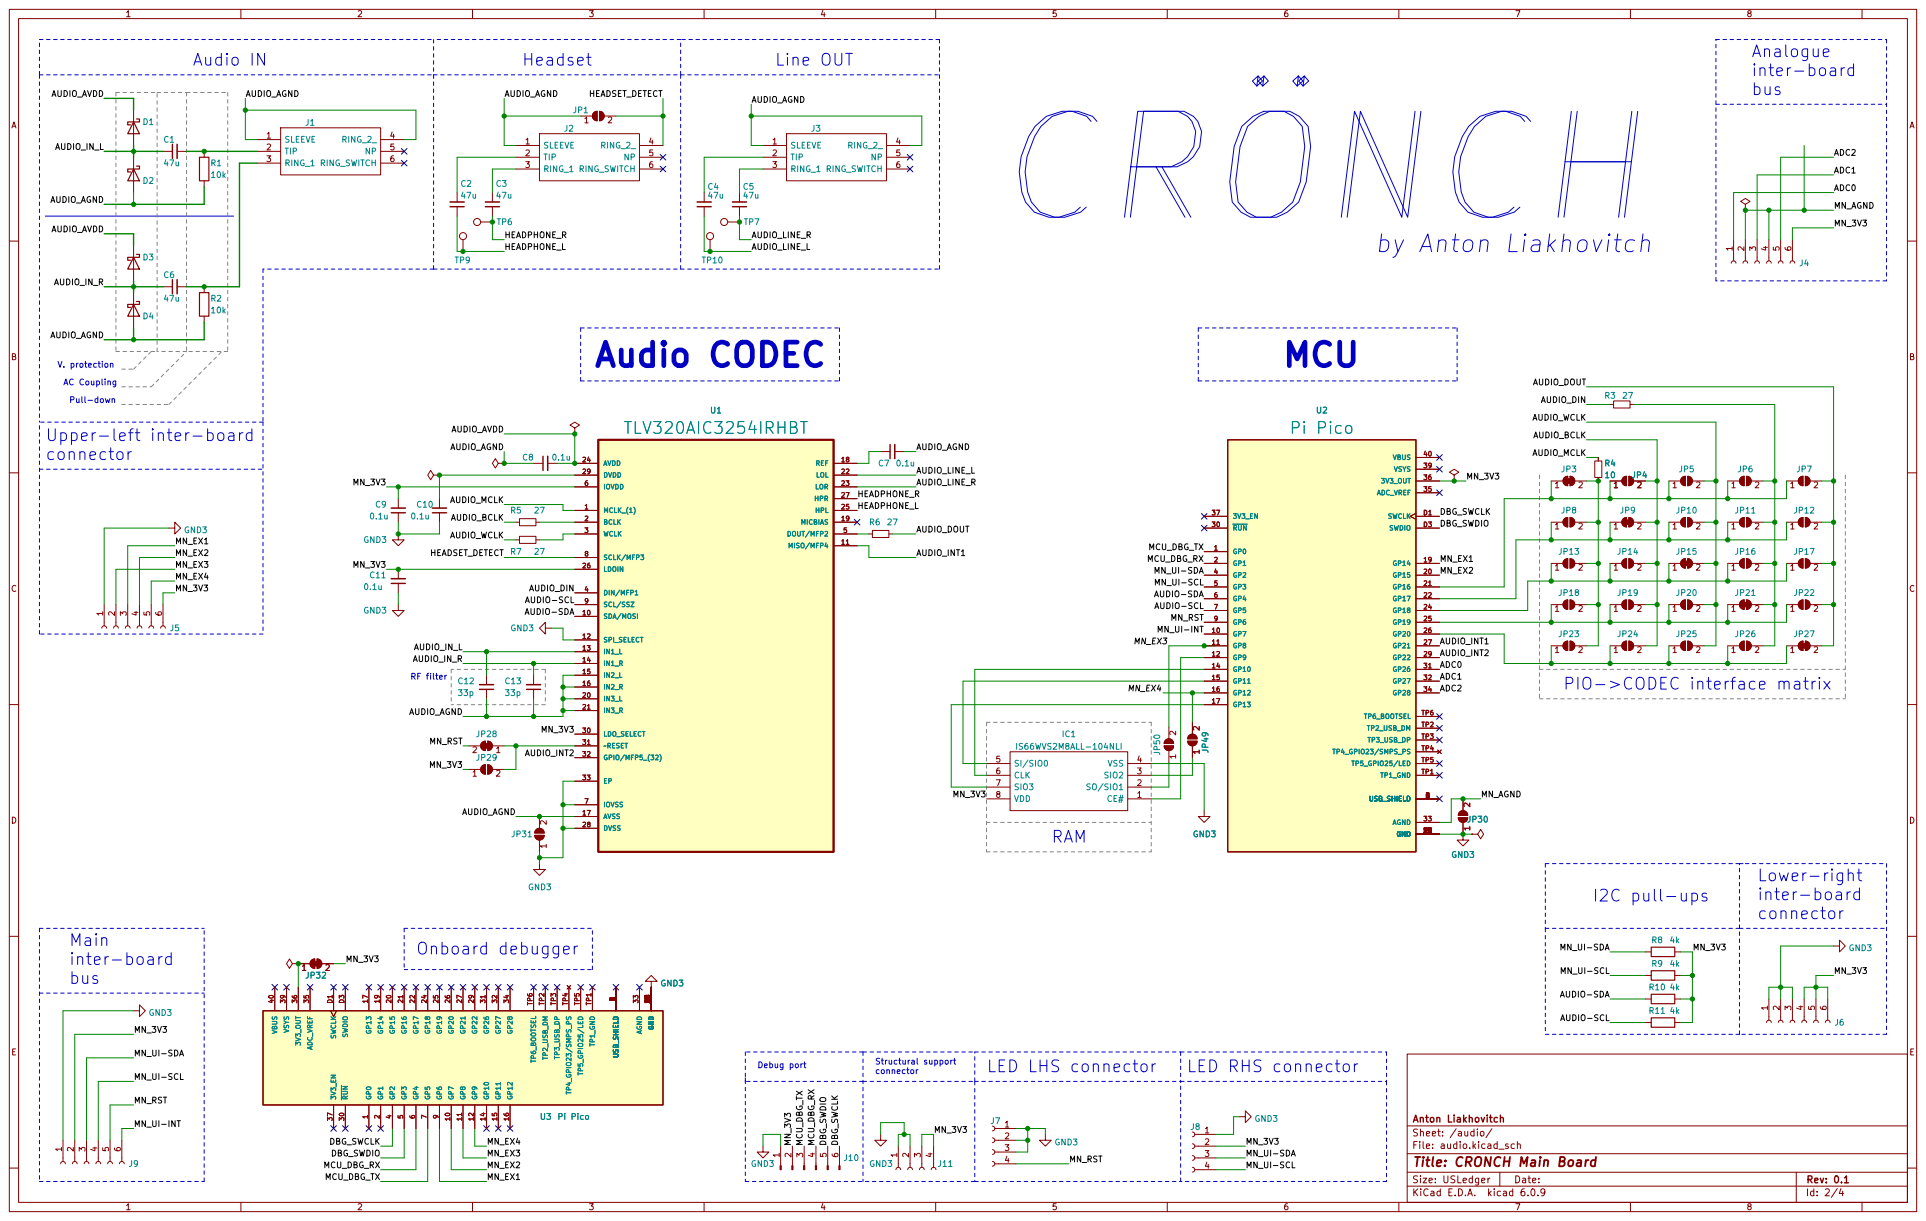
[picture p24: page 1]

V. protection
AC Coupling
Pull-down Upper-left inter-board

PIO->CODEC interface matrix

ABCD SWCLK D1 GND D2 SWDIO D3 TP1_GND TP1 TP2_USB_DM TP2 TP3_USB_DP TP3 TP4_GPIO23/SMPS_PS TP4 TP5_GPIO25/LED TP5 TP6_BOOTSEL TP6 GND3

2 GP15 20 GP16 21 GP17 22 GND 23 GP18 24 GP19 25 GP20 26 GP21 27 GND 28 GP22 293 ~{RUN} 30 GP26 31 GP27 32 AGND 33 GP28 34 ADC_VREF 35 3V3_OUT 36 3V3_EN 37 GND 38 VSYS 39 GP2

ABCD SWCLK D1 GND D2 SWDIO D3 TP1_GND TP1 TP2_USB_DM TP2 TP3_USB_DP TP3 TP4_GPIO23/SMPS_PS TP4 TP5_GPIO25/LED TP5 TP6_BOOTSEL TP6 U3 Pi Pico

Debug port

J7 1 4 | MN_RST

File: audio.kicad_sch Sheet: /audio/ Anton Liakhovitch

Id: 2/4 Title: CRONCH Main Board

# Upper-left inter-board

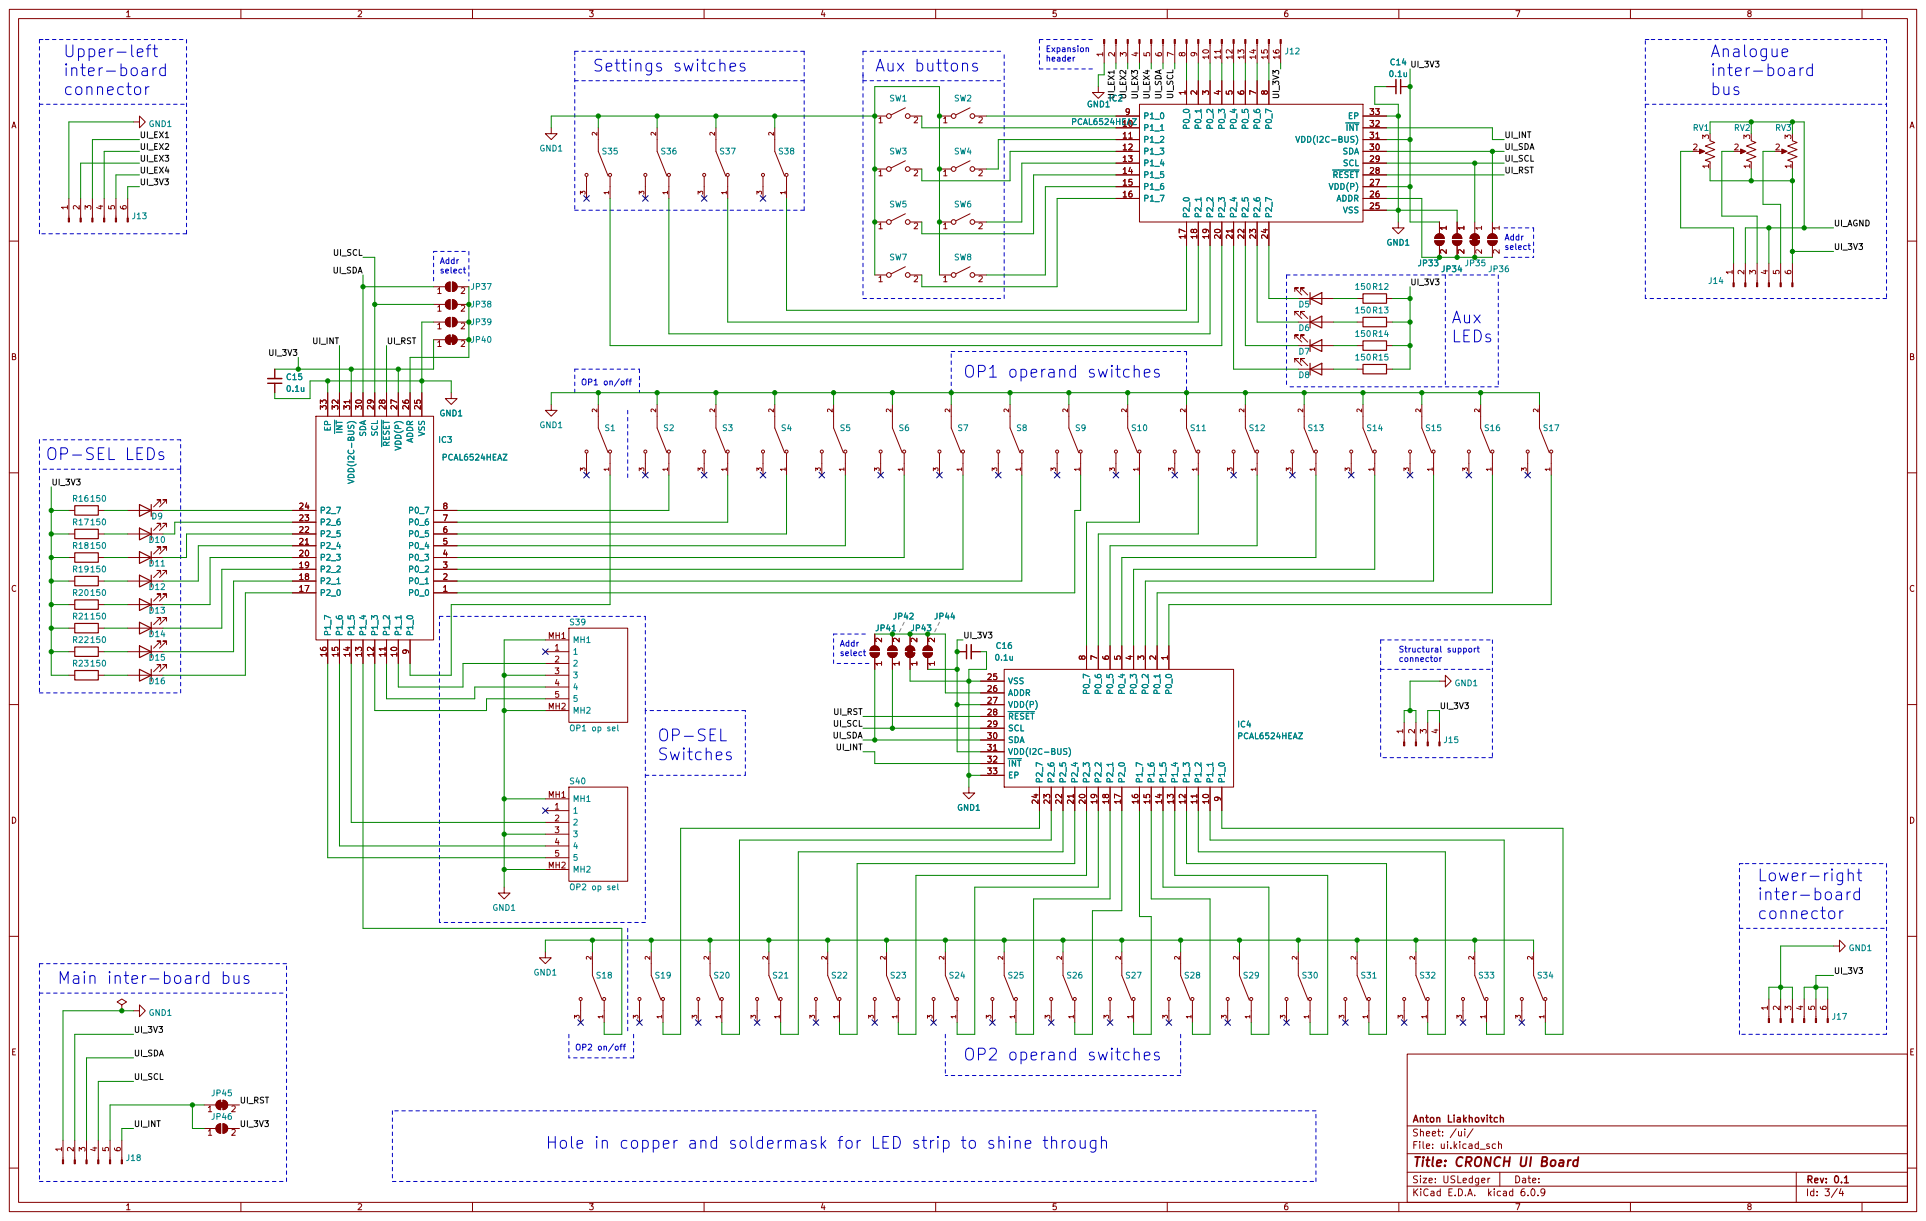
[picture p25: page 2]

2 P2_3 20 P2_4 21 P2_5 22 P2_6 23 P2_7 24 VSS 25 ADDR 26 VDD(P) 27 ~{RESET} 28 SCL 29 P0_2

3 SDA 30 VDD(I2C-BUS) 31 ~{INT} 32 EP 33 P0_3

Addr select OP1 operand switches

Addr select OP-SEL LEDs

Structural support connector Main inter-board bus

File: ui.kicad_sch Sheet: /ui/ Anton Liakhovitch

Hole in copper and soldermask for LED strip to shine through

Id: 3/4 Title: CRONCH UI Board

# 0.1u SDA

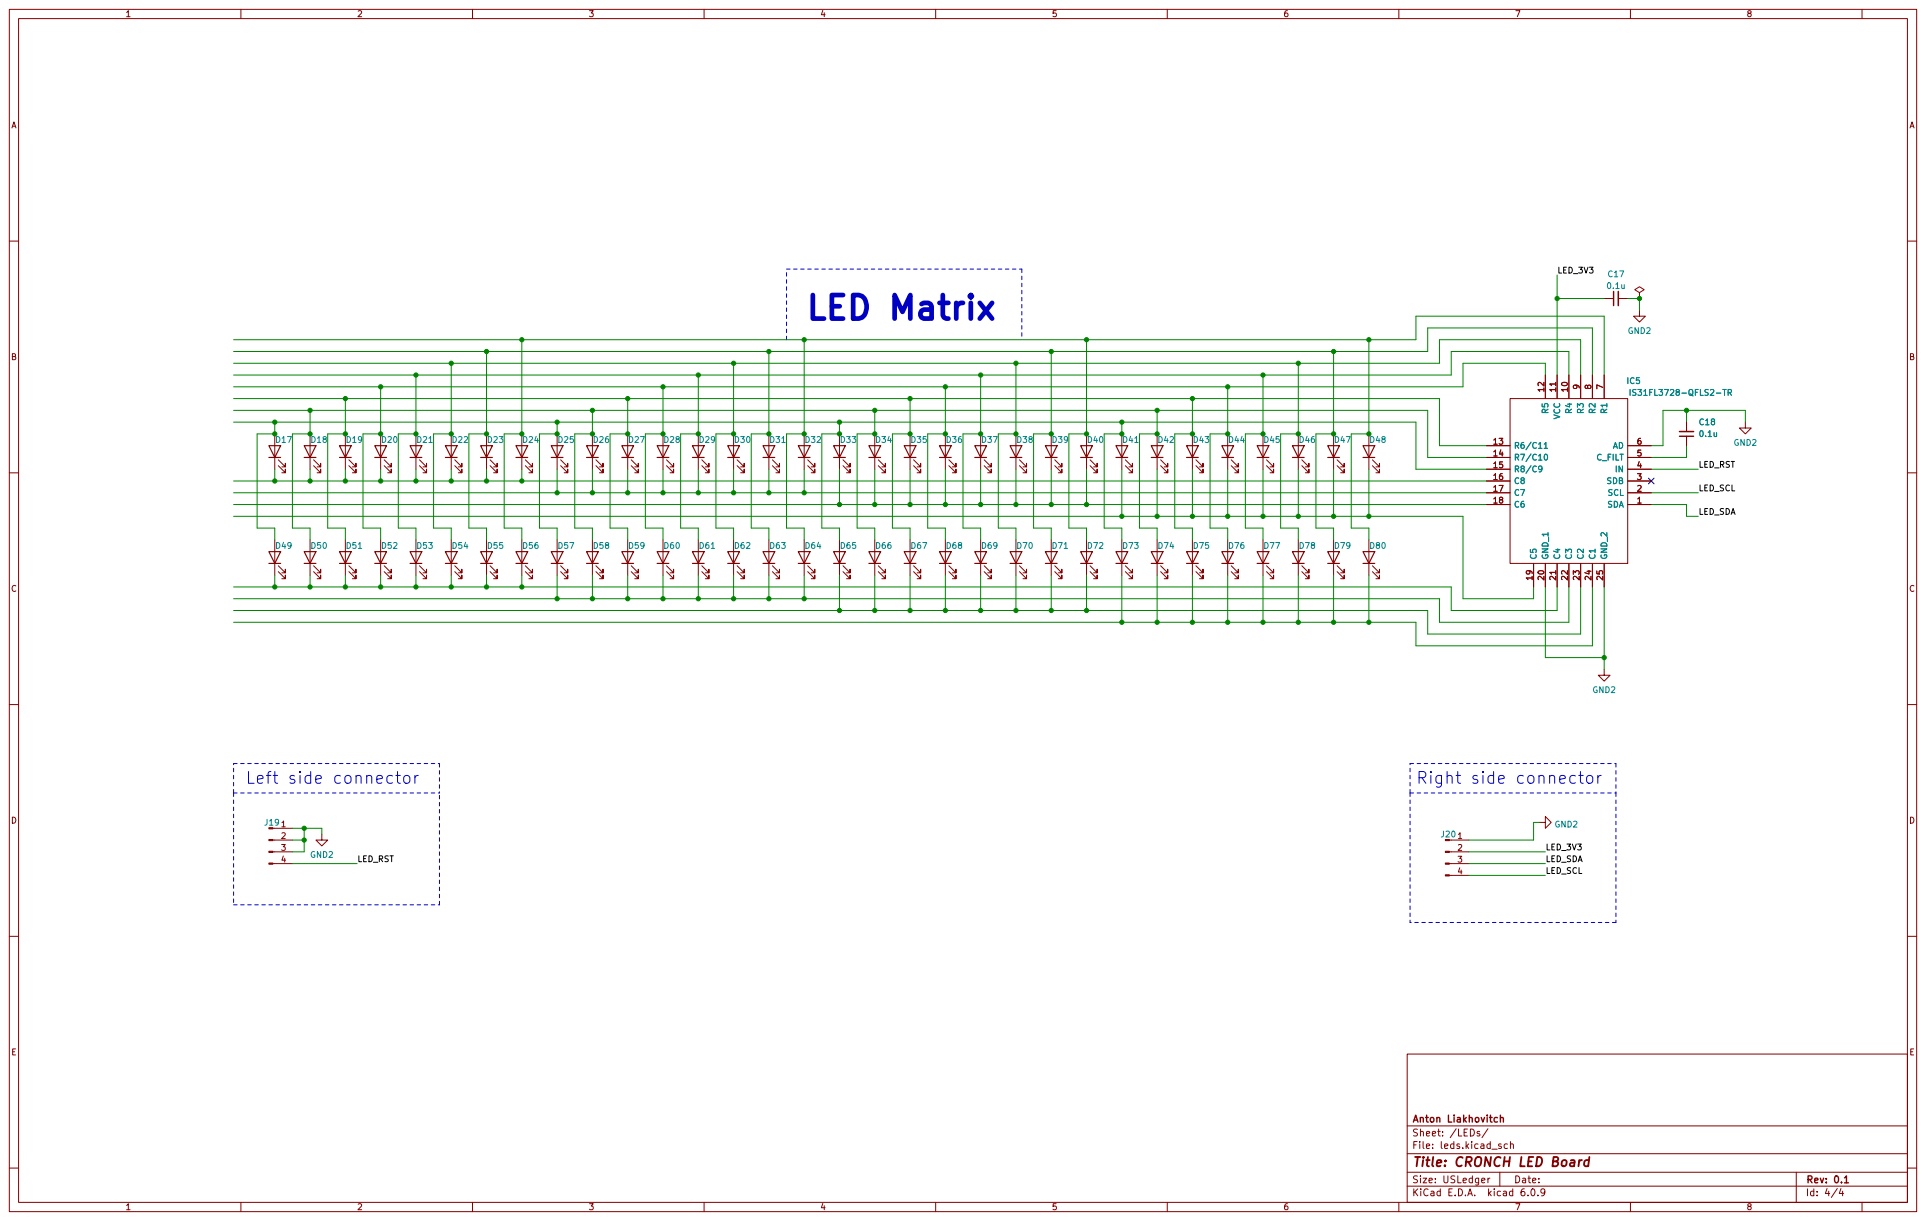
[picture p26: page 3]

File: leds.kicad_sch Sheet: /LEDs/ Anton Liakhovitch

Id: 4/4 Title: CRONCH LED Board

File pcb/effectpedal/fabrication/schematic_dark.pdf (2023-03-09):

## TP9C2

| | 10k C1 10k D3 D2

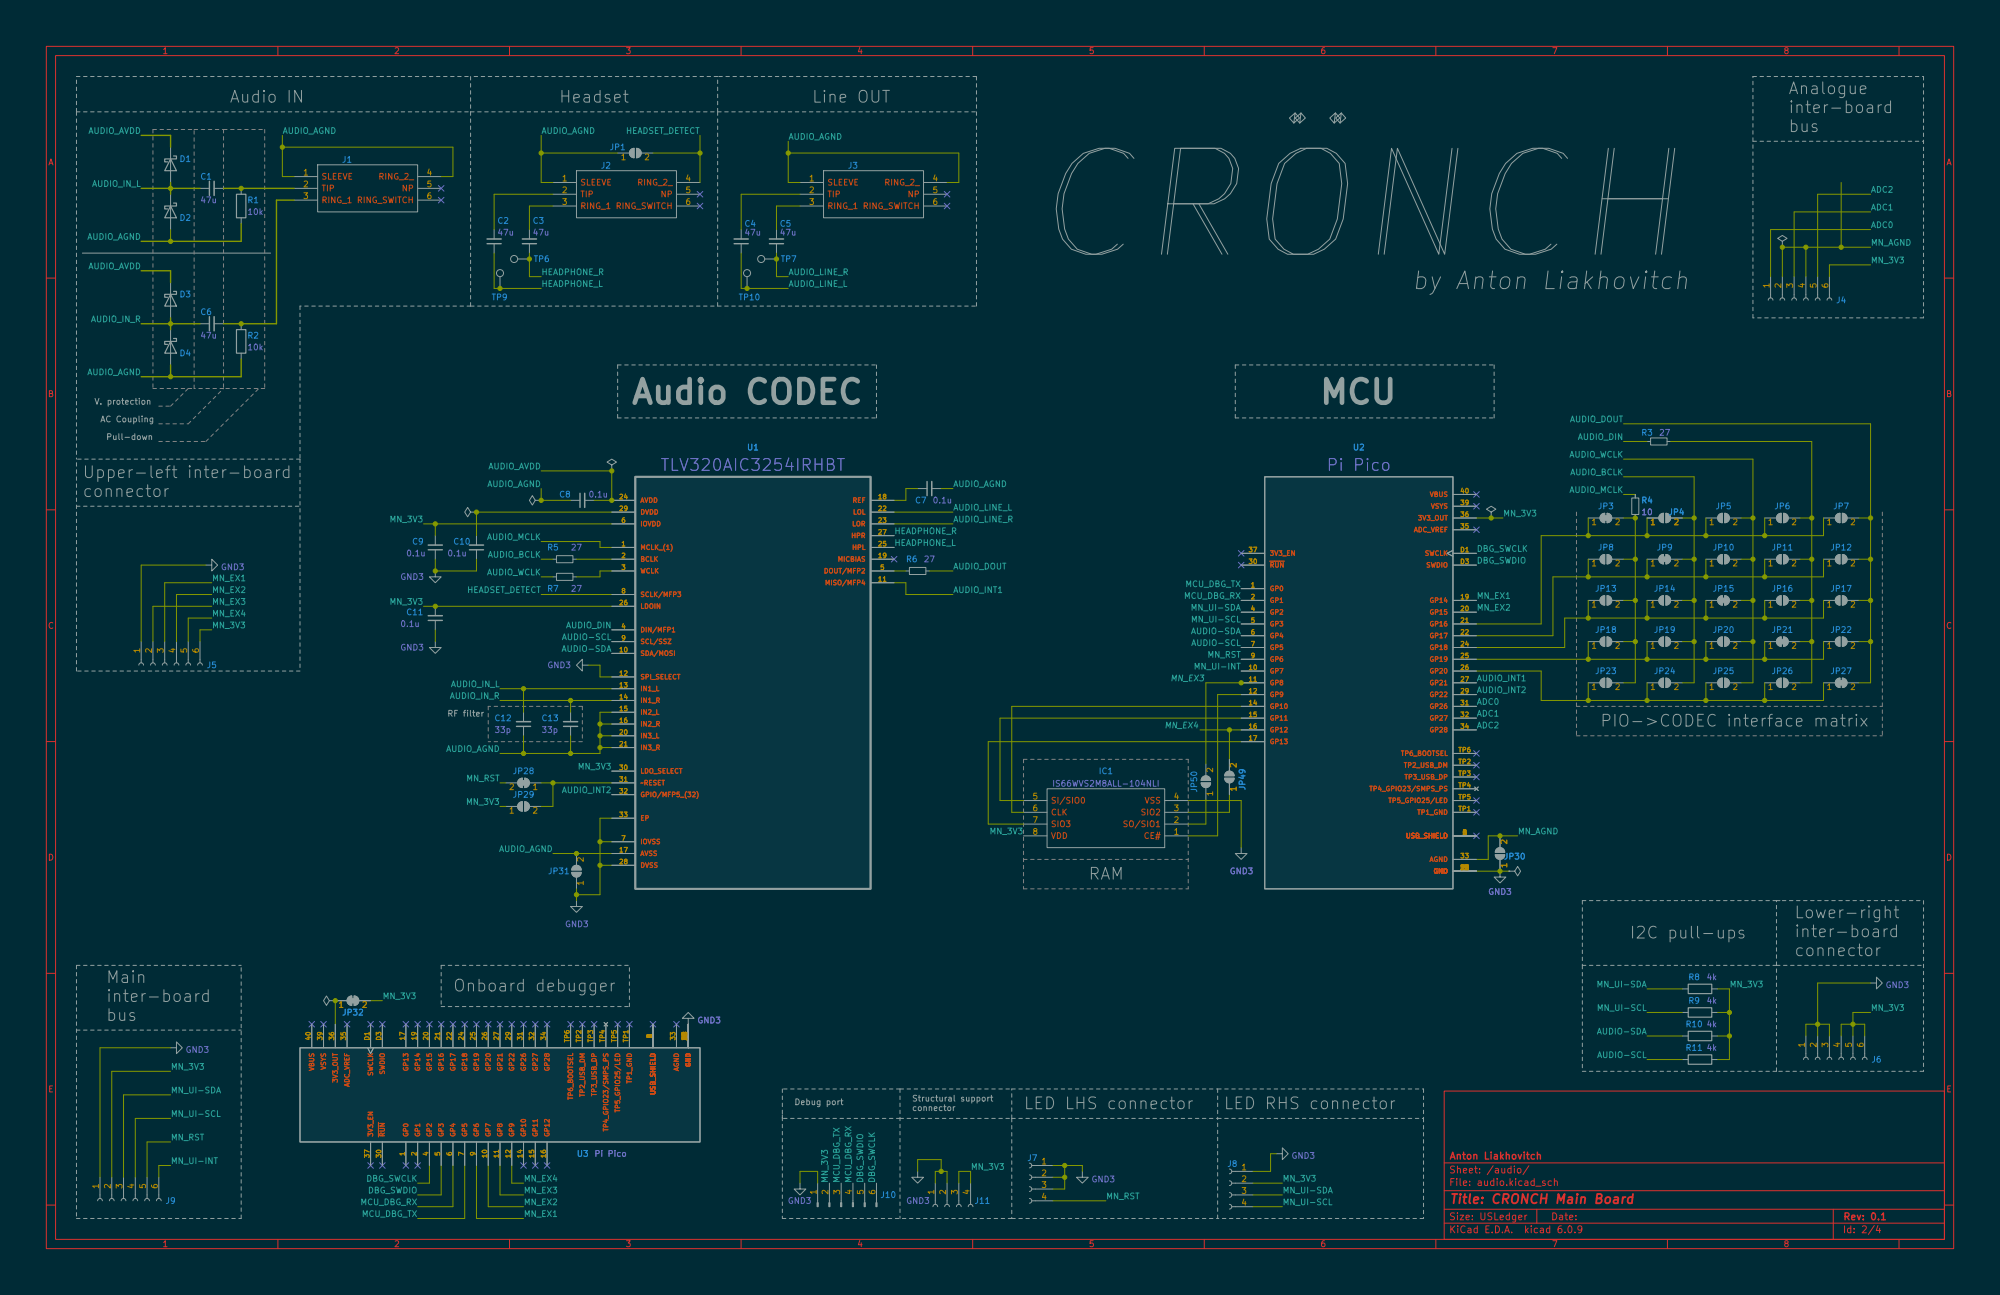
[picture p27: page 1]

þÿCRÖNCH by Anton Liakhovitch

AUDIO-SCL MN_UI-SDA MCU_DBG_RX MN_UI-SCL AUDIO_AVDD

connector Pull-down V. protection
AC Coupling

Upper-left inter-board

PIO->CODEC interface matrix

AUDIO_IN_L AUDIO_IN_R
RF filter Onboard debugger

ABCD SWCLK D1 GND D2 SWDIO D3 TP1_GND TP1 TP2_USB_DM TP2 TP3_USB_DP TP3 TP4_GPIO23/SMPS_PS TP4 TP5_GPIO25/LED TP5 TP6_BOOTSEL TP6 U3 Pi Pico GND3

ABCD SWCLK D1 GND D2 SWDIO D3 TP1_GND TP1 TP2_USB_DM TP2 TP3_USB_DP TP3 TP4_GPIO23/SMPS_PS TP4 TP5_GPIO25/LED TP5 TP6_BOOTSEL TP6 GND3

2 GP15 20 GP16 21 GP17 22 GND 23 GP18 24 GP19 25 GP20 26 GP21 27 GND 28 GP22 293 ~{RUN} 30 GP26 31 GP27 32 AGND 33 GP28 34 ADC_VREF 35 3V3_OUT 36 3V3_EN 37 GND 38 VSYS 39 GP2

Debug port

File: audio.kicad_sch Sheet: /audio/ Anton Liakhovitch

Id: 2/4 Title: CRONCH Main Board

# Upper-left inter-board

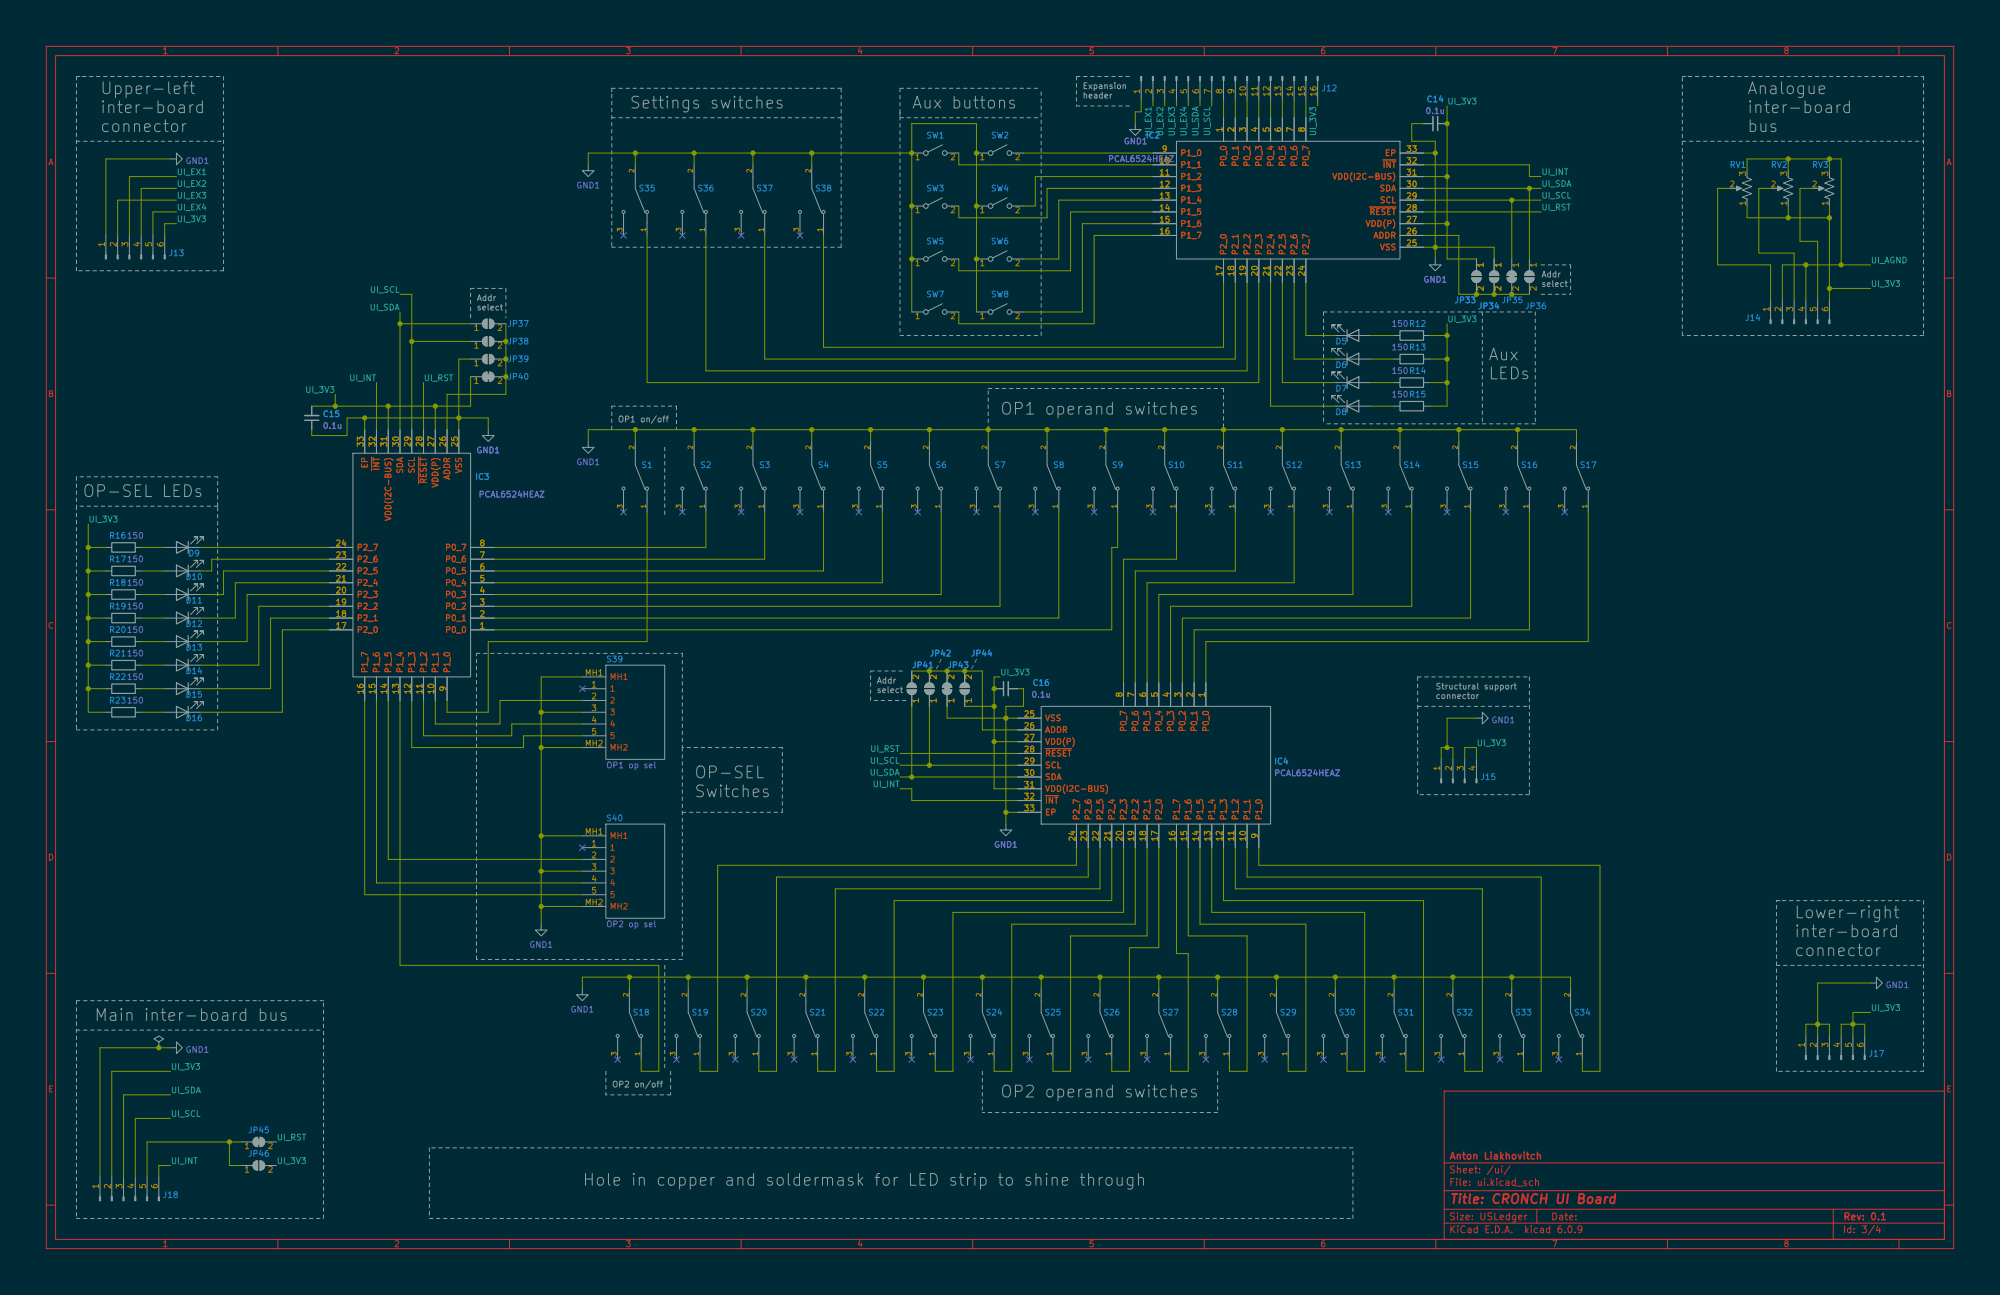
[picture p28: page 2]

2 P2_3 20 P2_4 21 P2_5 22 P2_6 23 P2_7 24 VSS 25 ADDR 26 VDD(P) 27 ~{RESET} 28 SCL 29 P0_2

3 SDA 30 VDD(I2C-BUS) 31 ~{INT} 32 EP 33 P0_3

Addr select OP1 operand switches

Addr select OP-SEL LEDs

Structural support connector Main inter-board bus

File: ui.kicad_sch Sheet: /ui/ Anton Liakhovitch

Hole in copper and soldermask for LED strip to shine through

Id: 3/4 Title: CRONCH UI Board

# 0.1u SDA

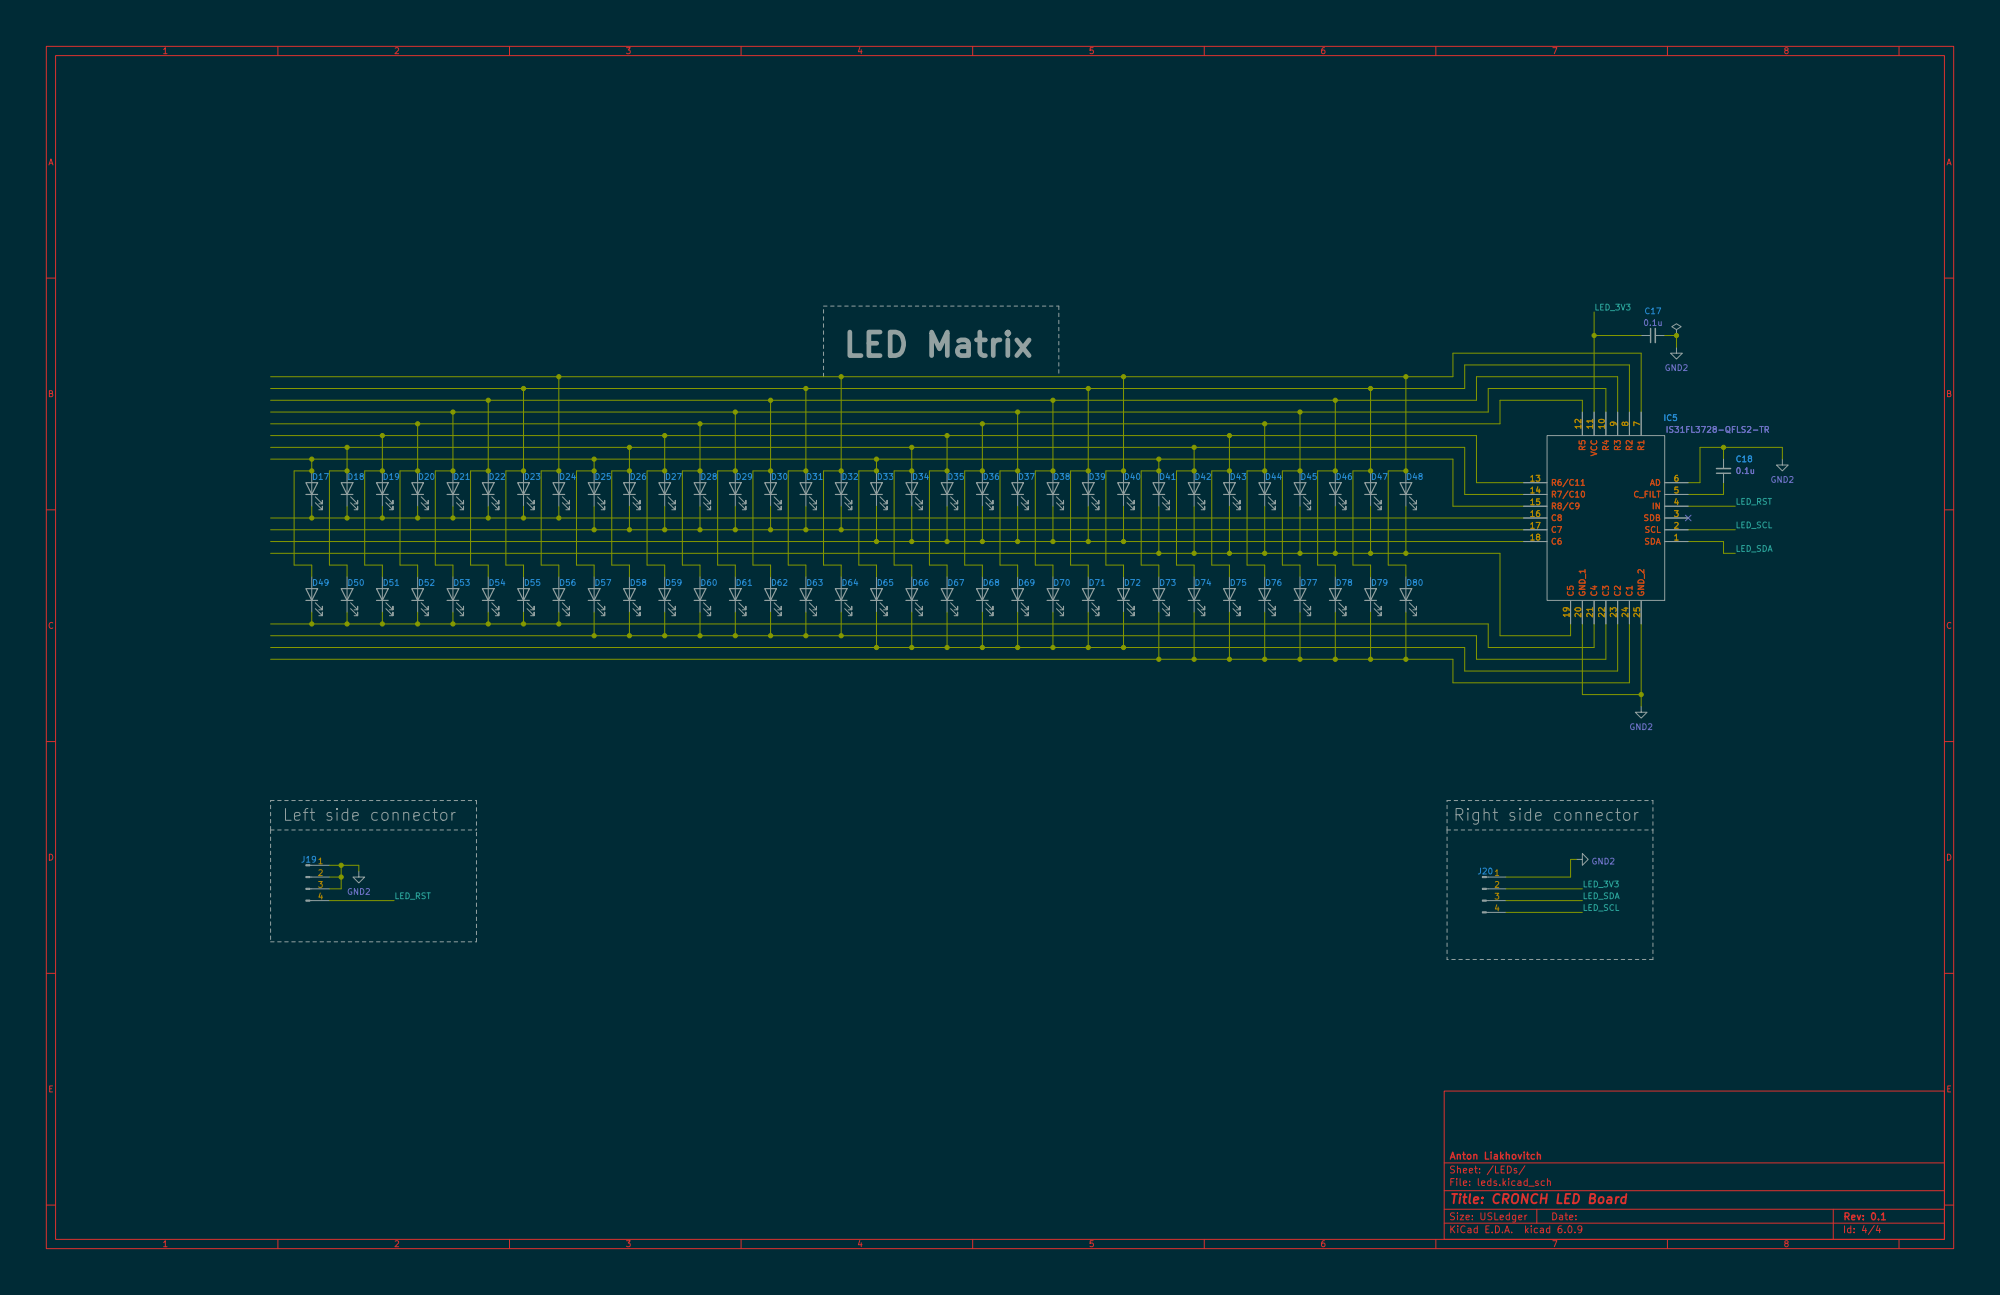
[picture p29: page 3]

File: leds.kicad_sch Sheet: /LEDs/ Anton Liakhovitch

Id: 4/4 Title: CRONCH LED Board

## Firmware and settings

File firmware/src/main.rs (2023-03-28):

#![crate_name = "cronch"]

//! # CRONCH
//! By Anton Liakhovitch

#![no_std]
#![no_main]

mod double_buf;
mod ui;
mod audio;
mod init;
mod panic;

use cortex_m::singleton;

use double_buf::{DoubleBuf, DoubleBufPort};

use rp_pico::entry;

// GPIO traits
use embedded_hal::{
    digital::v2::OutputPin,
    PwmPin,
};

use embedded_hal::prelude::*;

use fugit::RateExtU32;

use rp_pico::hal;
use hal::{
    prelude::*,
    adc::Adc,
    multicore::{Multicore, Stack},
    pac,
};

use audio::tlv320::init_tlv320;
use ui::{expanders, led_strip, knob};
use crate::audio::i2s;

// Reserve memory for Core 1's stack
// (Stack memory for Core 0 is reserved automatically)
static mut CORE1_STACK: Stack<4096> = Stack::new();

#[entry]
fn main() -> ! {
    // Acquire ownership of all peripherals
    let mut pac = pac::Peripherals::take().unwrap();
    // Acquire ownership of core peripherals
    let core = pac::CorePeripherals::take().unwrap();

    // Init watchdog
    let mut watchdog = hal::Watchdog::new(pac.WATCHDOG);

    // Init clocks with a 125MHz system clock
    let clocks = init_clocks!(pac, watchdog).unwrap();

    // Init systick timer and delay
    let mut delay = cortex_m::delay::Delay::new(core.SYST, clocks.system_clock.freq().to_Hz());
    let _timer = rp2040_hal::timer::Timer::new(pac.TIMER , &mut pac.RESETS);

    // Init single-cycle IO
    let mut sio = hal::Sio::new(pac.SIO);

    // Init GPIO
    let pins = rp_pico::Pins::new(
        pac.IO_BANK0,
        pac.PADS_BANK0,
        sio.gpio_bank0,
        &mut pac.RESETS,
    );

    // Init PWMs
    let mut pwm_slices = hal::pwm::Slices::new(pac.PWM, &mut pac.RESETS);

    // Set up global peripheral reset and reset all external peripherals
    let mut rst_pin = pins.gpio6.into_push_pull_output();
    rst_pin.set_low().unwrap();
    delay.delay_ms(5);
    rst_pin.set_high().unwrap();
    delay.delay_ms(5);

    // Create a statically allocated double buffer to share data between cores
    let intercore = singleton!(:DoubleBuf::<ui::UiOutput, ui::UiInput, 0, 1> = unsafe{
        DoubleBuf::new(||{Default::default()}, ||{Default::default()})
    }).unwrap();
    let (mut intercore_ui, mut intercore_audio) = intercore.split().unwrap();

    #[cfg(not(feature="headless"))]
    {
        // Init ADC
        let mut adc = Adc::new(pac.ADC, &mut pac.RESETS);
        let mut mix_knob = knob::Knob::new(pins.gpio26.into_floating_input(), 4);
        let mut clk_knob = knob::Knob::new(pins.gpio27.into_floating_input(), 4);
        let mut fdbk_knob = knob::Knob::new(pins.gpio28.into_floating_input(), 4);

        // Init UI I2C
        let mut ui_i2c = init_ui_i2c!(pins, pac, clocks);

        // Setup core 1
        let mut mc = Multicore::new(&mut pac.PSM, &mut pac.PPB, &mut sio.fifo);
        mc.cores()[1].spawn(unsafe { &mut CORE1_STACK.mem }, move || {
            // -- ALL CODE IN THIS SCOPE RUNS ON CORE1, IN PARALLEL WITH CORE0 --

            // Acquire core peripherals for Core 1
            let _core = unsafe { pac::CorePeripherals::steal() };
            // SIO peripherals are also duplicated for each core so stealing them is OK
            let sio = hal::Sio::new(unsafe { pac::Peripherals::steal().SIO });
            // Init 64-bit timebase timer
            let timer = rp2040_hal::timer::Timer::new(unsafe { pac::Peripherals::steal().TIMER }, &mut unsafe { pac::Peripherals::steal().RESETS });

            // Init LED strip
            let mut led_strip = led_strip::LedStrip::new(&mut ui_i2c, &timer, &sio.hwdivider, 800, 800).unwrap();

            // Init front panel IO expanders
            let expanders = expanders::Expanders::new(&mut ui_i2c).unwrap();

            let mut out: ui::UiOutput = Default::default();
            let mut input: ui::UiInput = Default::default();
            // Read the ADCs to stabilize the hysteresis state
            if let Some(n) = fdbk_knob.read(&mut adc).unwrap() { out.fdbk_knob = n };
            if let Some(n) = clk_knob.read(&mut adc).unwrap() { out.clk_knob = n };
            if let Some(n) = mix_knob.read(&mut adc).unwrap() { out.mix_knob = n };
            loop {
                led_strip.update(&mut ui_i2c, &out, &input).unwrap();

                read_panel!(out, ui_i2c, expanders, adc, fdbk_knob, clk_knob, mix_knob, led_strip);

                intercore_ui.rw(|w| { *w = out; }, |r| { input = *r; });
            }
        }).unwrap();

    } // End conditional compilation

    // Init TLV320AIC3254 MCLK signal
    init_audio_clk!(pwm_slices, pins);

    // Init audio I2C
    let mut audio_i2c = init_audio_i2c!(pins, pac, clocks);

    init_tlv320(&mut audio_i2c, &mut delay);

    // Init PSRAM
    let (mut psram_spi, mut psram_cs) = init_psram!(pins, pac, clocks, delay);

    // Write to SPI
    let addr: u32 = 0x05;
    let addr_bytes = addr.to_le_bytes();
    let mut buffer: [u8; 5] = [0x02, addr_bytes[2], addr_bytes[1], addr_bytes[0], 0x22];
    psram_cs.set_low().unwrap();
    psram_spi.transfer(&mut buffer).unwrap();
    psram_cs.set_high().unwrap();
    delay.delay_ms(1);

    let mut buffer: [u8; 6] = [0x0B, addr_bytes[2], addr_bytes[1], addr_bytes[0], 0x00, 0x00];
    psram_cs.set_low().unwrap();
    psram_spi.transfer(&mut buffer).unwrap();
    psram_cs.set_high().unwrap();

    let mut out: ui::UiInput = Default::default();
    let mut input: ui::UiOutput = Default::default();

    let mut sample = (0i32, 0i32);

    let (mut pio, sm0, sm1, sm2, sm3) = pac.PIO0.split(&mut pac.RESETS);
    let mut i2s = i2s::I2S::new(&mut pio, pins.gpio17, pins.gpio18, pins.gpio19, pins.gpio20, sm0, sm1, sm2, sm3);
    // Turn off PIO input synchronizers. This is necessary to allow PIO inputs to run at full speed so we can support 192KHz 32bit audio
    unsafe{ pac::Peripherals::steal().PIO0.input_sync_bypass.write(|w| w.bits(0xFFFFFFFF)); }

    loop {

        i2s.write_left(sample.0);
        i2s.write_right(sample.1);
        sample.0 = i2s.read_left();
        sample.1 = i2s.read_right();

        out.write_addr = out.write_addr.wrapping_add(1);
        out.read_addr = out.write_addr;
        intercore_audio.rw(|w|{ *w = out; }, |r|{ input = *r; });

        cortex_m::asm::delay(360); // This represents the remaining CPU budget
        // Note: the actual available budget is the delay value x1.5 since asm::delay takes
        // 1.5 * (input) cycles on Cortex-M0.
        // The theoretical maximum budget is:
        // (64 bits/sample) * (125MHz sysclk / 12.5MHz I2S clock) = 640 CPU cycles per sample
    }
}

// End of file

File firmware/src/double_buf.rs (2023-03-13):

use rp_pico::hal::sio::{SpinlockValid, Spinlock};
use core::{
    marker::PhantomData,
    cell::UnsafeCell,
    sync::atomic::{compiler_fence, Ordering,},
};

/// Specifies which Spinlock a DoubleBufPort is currently holding
enum HeldLock<const A: usize, const B: usize> where
    Spinlock<A>: SpinlockValid,
    Spinlock<B>: SpinlockValid,
{
    A(Spinlock<A>),
    B(Spinlock<B>),
}

/// A single data buffer. Each DoubleBuf has two of these.
struct DataBuf<LTR, RTL>{
    /// A buffer for transferring data from the *Left* side to the *Right* side
    ltr: LTR,
    /// True if 'ltr' has not yet been read by the *Right* side
    ltr_fresh: bool,
    /// A buffer for transferring data from the *Right* side to the *Left* side
    rtl: RTL,
    /// True if 'rtl' has not yet been read by the *Left* side
    rtl_fresh: bool,
}

/// An asymmetrical, asynchronous, bidirectional double buffer.
/// Can be split into a *Left* and a *Right* to transfer data between the RP2040 cores.
/// Uses HW spinlocks for synchronization.
/// "A" and "B" parameters are integers from 0-31 specifying which spinlocks should be used.
pub struct DoubleBuf<LTR, RTL, const A: usize, const B: usize> where
    Spinlock<A>: SpinlockValid,
    Spinlock<B>: SpinlockValid,
    LTR: Send, LTR: Sync, RTL: Send, RTL: Sync
{
    buf_a: UnsafeCell<DataBuf<LTR, RTL>>,
    buf_b: UnsafeCell<DataBuf<LTR, RTL>>,
    is_split: bool,
    lock_a: PhantomData<Spinlock<A>>,
    lock_b: PhantomData<Spinlock<B>>,
}

impl <LTR, RTL, const A: usize, const B: usize>DoubleBuf<LTR, RTL, A, B> where
    Spinlock<A>: SpinlockValid,
    Spinlock<B>: SpinlockValid,
    LTR: Send, LTR: Sync, RTL: Send, RTL: Sync
{
    /// Create a new DoubleBuffer.
    /// This function is *unsafe* because the caller must assert that the provided spinlocks are not used for anything else.
    ///
    /// # Generic Parameters
    /// * 'LTR' - Whatever type of data will be transferred from the *Left* side of the buffer to the *Right* side. Usually a struct.
    /// * 'RTL' - Whatever type of data will be transferred from the *Right* side of the buffer to the *Left* side. Usually a struct.
    /// * 'A' and 'B' are integers from 0-31 specifying which spinlocks should be used. Must be explicitly specified.
    ///
    /// # Arguments
    ///
    /// * 'new_ltr' - Closure that constructs the left-to-right buffer.
    /// * 'new_rtl' - Closure that constructs the right-to-left buffer.
    // Note: We need to take closures as arguments so that we can make two copies of the initial
    //       values without requiring that the types be Copy.
    pub unsafe fn new<F, G>(new_ltr: F, new_rtl: G)->Self where
        F: Fn() -> LTR, G: Fn() -> RTL,
    {
        DoubleBuf{
            buf_a: DataBuf{
                ltr: new_ltr(),
                ltr_fresh: false,
                rtl: new_rtl(),
                rtl_fresh: false,
            }.into(),
            buf_b: DataBuf{
                ltr: new_ltr(),
                ltr_fresh: false,
                rtl: new_rtl(),
                rtl_fresh: false,
            }.into(),
            is_split: false,
            lock_a: PhantomData,
            lock_b: PhantomData,
        }
    }

    /// Splits the DoubleBuffer into a *Left* side and a *Right* side.
    /// Can only be called once; duplicate invocations will return None.
    /// Note that the original DoubleBuffer still owns the data and must live longer than either *Left* or *Right*.
    pub fn split(&mut self) -> Option<(Left<'_, LTR, RTL, A, B>, Right<'_, LTR, RTL, A, B>)>{
        // Make sure that spinlock B is actually free
        let _foo = Spinlock::<B>::try_claim().unwrap();
        drop(_foo);
        match self.is_split{
            true => {None}
            false => {
                self.is_split = true;
                Some((
                        Left{
                            buf_a: &self.buf_a,
                            lock_a: PhantomData,
                            buf_b: &self.buf_b,
                            lock_b: PhantomData,
                            // Claim the original spinlock, panicking if it fails
                            held_lock: HeldLock::A(Spinlock::<A>::try_claim().unwrap())
                        },
                        Right{
                            buf_a: &self.buf_a,
                            lock_a: PhantomData,
                            buf_b: &self.buf_b,
                            lock_b: PhantomData,
                        },
                ))
            }
        }

    }
}

/// One half of an asynchronous asymmetrical bidirectional double buffer.
/// This can be either a *Left* or a *Right*.
pub trait DoubleBufPort{
    type R;
    type W;

/// Read and write to a DoubleBuf.
/// # Arguments
///
/// * 'write' - Closure which writes data to the buffer. This will run every single time.
///
/// * 'read' - Closure which reads data from the buffer. This will *not* run if no fresh data is available!
///
/// When called on a *Left*, rw may briefly block waiting for the other side of the buffer to release.
/// When called on a *Right*, rw should never block.
/// No matter what, the write operation always happens first.
    fn rw<F, G>(&mut self, write: F, read: G) where
      F: FnMut(&mut Self::W), G: FnMut(& Self::R);
}

/// The *Left* side of a DoubleBuffer. Implements DoubleBufPort for reading and writing.
pub struct Left<'a, LTR, RTL, const A: usize, const B: usize> where
Spinlock<A>: SpinlockValid,
Spinlock<B>: SpinlockValid,
{
    buf_a: &'a UnsafeCell<DataBuf<LTR, RTL>>,
    lock_a: PhantomData<Spinlock<A>>,
    buf_b: &'a UnsafeCell<DataBuf<LTR, RTL>>,
    lock_b: PhantomData<Spinlock<B>>,
    held_lock: HeldLock<A, B>,
}

unsafe impl <LTR, RTL, const A: usize, const B: usize> Send for Left <'_, LTR, RTL, A, B> where
    Spinlock<A>: SpinlockValid,
    Spinlock<B>: SpinlockValid,
{}

unsafe impl <LTR, RTL, const A: usize, const B: usize> Sync for Left<'_, LTR, RTL, A, B> where
    Spinlock<A>: SpinlockValid,
    Spinlock<B>: SpinlockValid,
{}
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

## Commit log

2023-02-05 Made progress on the PCB
    [CUI_DEVICES_TS04-66-43-BK-100-SMT.step, EDI2CAP.CFG, PCAL6524HEAZ.SchLib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]
2023-02-06 Mostly finished PCB
    [audio.kicad_sch, effectpedal.csv, effectpedal.kicad_sch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]
2023-03-09 Added more test code and deleted some useless stuff
    [audio.kicad_sch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]
2023-03-09 Cleaned up repository mess
    [EDI2CAP.CFG, PTV09A-4020U-B103.SchLib, PTV09A4015FB103.PcbLib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]
2023-03-13 Simplification and refactoring, UI driver code
2023-03-26 Initial I2S implementation (does not work yet)
    [i2s.rs, main.rs, mod.rs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]
